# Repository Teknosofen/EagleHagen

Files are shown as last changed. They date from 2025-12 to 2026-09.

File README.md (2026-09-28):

# Eaglehagen CO₂ Monitor

ESP32-S3 (LilyGO T-Display S3) replacement for a legacy PIC16F876A/LabVIEW setup. It reads a MedAir MaCO2-V3 side-stream CO₂ analyser plus O₂ and volume sensors, and shows the data on the built-in screen, on a phone or tablet over WiFi, and as a serial stream over USB.

All documentation is public in this repository: **https://github.com/Teknosofen/EagleHagen**

| Document | For |
|---|---|
| [USER_GUIDE.md](USER_GUIDE.md) | Operating the device: screen, buttons, web page, data export, PC connection, troubleshooting |
| [documentation/DESIGN_REFERENCE.md](documentation/DESIGN_REFERENCE.md) | Hardware, sensor protocol, firmware architecture, interfaces, build setup, history |
| [documentation/Eaglehagen_Basic_Setup.pptx](documentation/Eaglehagen_Basic_Setup.pptx) | Printable basic-setup handout (9 pages) |
| [documentation/Images/](documentation/Images/) | Photos of the unit, closed and opened |
| [documentation/Mech CAD/](documentation/Mech%20CAD/) | Enclosure model (Autodesk Fusion 360 archive, `.f3z`) |
| [tools/Eaglehagen_Serial_Monitor.html](tools/Eaglehagen_Serial_Monitor.html) | Stand-alone PC monitor over USB: accepts both output formats (LabVIEW and ASCII), records to CSV. Also downloadable from the device's web page (embedded in the firmware at build time). Open in Chrome/Edge; add `#demo` for synthetic data |

**Quick start:** power on → join WiFi `EAGLEHAGEN` (no password) → open `http://eaglehagen.local` (or `http://192.168.4.1`).

**Build:** `pio run -t upload` (PlatformIO). No library edits are needed; the display setup is in [include/TFT_eSPI_Setup.h](include/TFT_eSPI_Setup.h).

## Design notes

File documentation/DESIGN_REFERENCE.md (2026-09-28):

# Eaglehagen CO₂ Monitor — Design & Technical Reference

This is the single design reference for the Eaglehagen monitor: hardware, sensor protocol, firmware architecture, interfaces, build setup and history. It combines the earlier documents `TECHNICAL_OVERVIEW.md`, `SOFTWARE_ARCHITECTURE.md`, `ESP32_MedAir_Implementation.md`, `CO2_Analyzer_Serial_Interface.md`, `LIBRARY_DEPENDENCIES.md`, `LOGO_IMPLEMENTATION_FINAL.md`, `Setup.txt` and `README.md`. Those files remain available in git history (last present in commit `65a4f93`).

For operating instructions, see [../USER_GUIDE.md](../USER_GUIDE.md).

**Repository:** all documentation, the firmware source and the PC monitor page are in the public repository **https://github.com/Teknosofen/EagleHagen**. The latest version of this document is always there.

Where the older documents contradicted each other, **the current source code (`src/`, `include/`) was taken as the truth**. Superseded statements are listed in [§13](#13-superseded-design-decisions-and-corrections) so the history isn't lost.

---

## Contents

1. [Background and goals](#1-background-and-goals)
2. [Hardware](#2-hardware)
3. [MaCO2-V3 CO₂ sensor and protocol](#3-maco2-v3-co-sensor-and-protocol)
4. [Legacy PIC16F876A system](#4-legacy-pic16f876a-system)
5. [Firmware architecture](#5-firmware-architecture)
6. [USB host output (LabVIEW / ASCII)](#6-usb-host-output-labview--ascii), including the PC monitor page (§6.4)
7. [WiFi and web interface](#7-wifi-and-web-interface)
8. [LCD user interface](#8-lcd-user-interface)
9. [Configuration constants](#9-configuration-constants)
10. [Build environment and libraries](#10-build-environment-and-libraries)
11. [Testing and developer troubleshooting](#11-testing-and-developer-troubleshooting)
12. [Future enhancements](#12-future-enhancements)
13. [Superseded design decisions and corrections](#13-superseded-design-decisions-and-corrections)

---

## 1. Background and goals

The project replaces a roughly 20-year-old monitoring setup built for Dr. Eaglehagen (Örnhagen). In that setup a **PIC16F876A** combined data from a **MedAir MaCO2-V3** CO₂ analyser with two analog readings (O₂ and volume) and sent them to a PC running **LabVIEW**.

Goals of the ESP32 replacement:
- One device replaces the PIC board and the need for a PC during normal monitoring.
- Local display (TFT) and remote display (WiFi web page on phone or tablet).
- USB virtual COM port with a PIC-style data stream, so the existing LabVIEW program can keep working.
- Full bidirectional control of the analyser (start pump, zero calibration) from the web, USB or a hardware button.

### Old vs new signal flow

**Legacy (split serial):**
```
                    ┌─────────────────────┐
          ┌────────>│  MedAir MaCO2-V3    │
          │  TX     │   CO2 Analyzer      │
    Host/LabVIEW    └──────────┬──────────┘
          │                    │ TX (data out) 9600 8N1
          │         ┌──────────▼──────────┐
          │  RX     │  PIC16F876A         │◄─── AN0 (O2 sensor)
          └─────────┤  RX: from MaCO2     │◄─── AN1 (Volume sensor)
                    │  TX: to host        │
                    └─────────────────────┘
1. Host TX ──► MaCO2 RX       (commands; bypasses PIC completely)
2. MaCO2 TX ──► PIC RX        (8-byte packets)
3. PIC samples AN0/AN1, combines, PIC TX ──► Host RX
```
The PIC never saw the commands. It only received and enriched data.

**New (ESP32):**
```
MaCO2-V3 ◄──UART1 (bidirectional, 9600)──► ESP32-S3 (T-Display S3)
O2 sensor ──► GPIO1 ADC                      │  ├─ TFT 170×320
Vol sensor ─► GPIO2 ADC                      │  ├─ USB-C CDC ◄──► PC / LabVIEW (data + commands)
                                             │  └─ WiFi AP   ◄──► browsers (data + commands)
```
- The ESP32 owns the full UART link, so commands are visible and logged.
- The onboard 12-bit ADC replaces the PIC's AN0/AN1.
- USB-C provides power, programming, debug output and the LabVIEW data stream.

### Operating modes

| Mode | Topology | Use |
|---|---|---|
| USB only | MaCO2 ↔ ESP32 ↔ USB-C ↔ PC/LabVIEW | Drop-in replacement for PIC |
| WiFi only | MaCO2 ↔ ESP32 ↔ WiFi ↔ browser | Standalone bedside monitoring, no PC |
| Dual | Both at once | LabVIEW logging plus quick checks on a phone |
| USB + PC monitor page | MaCO2 ↔ ESP32 ↔ USB-C ↔ Chrome/Edge page (§6.4) | Live display and unlimited CSV recording on a PC, no LabVIEW |

### Migration plan (from original design)

1. **Parallel testing:** keep the PIC system, build the ESP32, verify LabVIEW data against the PIC output.
2. **Soft migration:** use the ESP32 normally and keep the PIC as backup.
3. **Full migration:** retire the PIC hardware.
4. **Web-first (optional):** move away from LabVIEW and export data from the web UI.

Hardware migration: remove the PIC board, add the T-Display S3, connect the O₂ and volume sensors to the ESP32 ADC (with dividers if they output 5 V), and replace the old RS-232 cable with one USB-C cable. The MaCO2 serial link (9600 baud) is unchanged.

```
Old:  MaCO2 TX → PIC RX;  PIC TX → RS232 → PC;  PC → MaCO2 RX;  O2 → AN0;  Vol → AN1
New:  MaCO2 TX → ESP32 UART1 RX (level shifted);  ESP32 UART1 TX → MaCO2 RX;
      O2 → GPIO1;  Vol → GPIO2;  ESP32 USB-C → PC (virtual COM)
```

---

## 2. Hardware

### 2.1 LilyGO T-Display S3

- ESP32-S3 dual-core, 240 MHz, WiFi/Bluetooth, 16 MB flash, OPI PSRAM
- 1.9" ST7789 TFT, 170×320, driven over an **8-bit parallel bus** (TFT_eSPI setup 206), used in portrait orientation
- Two push buttons: **GPIO0 (BOOT)** and **GPIO14**
- USB-C with native USB CDC (programming, debug, host data, 5 V power)
- Pin-layout picture: [Lilygo-T-display_pinlayout.webp](Lilygo-T-display_pinlayout.webp)

### 2.2 Pin assignment (current firmware)

| Pin | Function | Notes |
|-----|---|---|
| GPIO 17 | UART1 TX → MaCO2 RX | 9600 8N1, direct 3.3 V drive |
| GPIO 18 | UART1 RX ← MaCO2 TX | 9600 8N1, **via level shifter** |
| GPIO 1 | ADC — O₂ sensor | 12-bit, 11 dB attenuation |
| GPIO 2 | ADC — Volume sensor | 12-bit, internal weak pull-down enabled |
| GPIO 14 | Button — pump start, labelled **"Restart pump"** | INPUT_PULLUP, interrupt driven |
| GPIO 0 | Button — output-format toggle (BOOT), labelled **"Select output"** | INPUT_PULLUP, interrupt driven; strapping pin |
| GPIO 15 | TFT/peripheral power enable | OUTPUT, driven HIGH at start |
| GPIO 38 | TFT backlight | Handled by TFT_eSPI |
| GPIO 5–8 (+ data bus) | TFT parallel interface (RST=5, CS=6, DC=7, WR=8) | Pre-wired on the board |

### 2.3 Power supply

```
+12 V in ──┬──► MaCO2 sensor (+12 V)
           └──► 7805 ──► +5 V ──► ESP32 USB-C / 5 V
                [100 nF + 10 µF on input and output]
```
- **7805** (TO-220): input 7–35 V, output 5 V at up to 1 A. Add a heatsink if the load exceeds about 500 mA. If it runs too hot, use a buck converter (e.g. LM2596).
- **Power budget (estimated):** MaCO2 about 200–300 mA at 12 V. ESP32-S3 about 200–300 mA at 5 V (WiFi about 80 mA of that), backlight about 100 mA. Total at 5 V is about 300–400 mA.
- The board can also be powered from the PC over USB-C alone, for example on the bench.
- Option: 18650 Li-ion battery for portable use (not implemented).

### 2.4 Level shifting (MaCO2 5 V TTL ↔ ESP32 3.3 V)

**MaCO2 TX → ESP32 RX:** resistor and Zener clamp.
```
MaCO2 TX (5 V) ── 1 kΩ ──┬──► ESP32 GPIO18 (RX)
                         │
                   3.3 V Zener (1N5226B / BZX79-C3V3), cathode to signal
                         │
                        GND
```
This is simple and reliable at 9600 baud.

**ESP32 TX → MaCO2 RX:** direct connection. 3.3 V is above the 5 V TTL high threshold (about 2.0 V).

**Alternative:** a 74LVC245 powered from 3.3 V (5 V-tolerant inputs), with DIR = HIGH and OE = LOW.

### 2.5 Analog inputs

- ESP32-S3 SAR ADC, 12 bits (0–4095), 11 dB attenuation (usable range about 0–3.1 V). Accuracy is about ±2 % and up to about 83 kS/s.
- Voltage correction uses the ESP-IDF 5 **`adc_cali` curve-fitting** scheme (eFuse based), with a linear fallback. The legacy `esp_adc_cal` API **must not** be used: with Arduino core 3.x, linking it next to the driver behind `analogRead()` makes ESP-IDF abort at boot (`check_adc_oneshot_driver_conflict`).
- **O₂ sensor:** Servomex **PM1111E** paramagnetic cell (no reagent consumption, no drift). Linear 0–1 V output, connected directly.
- **Volume sensor:** analog pressure/flow transducer.
- If a sensor outputs 0–5 V, add a divider: R1 = 10 kΩ (series) and R2 = 20 kΩ (to GND) gives 3.33 V at 5 V. 10k/22k gives 3.44 V, which is marginal.
- Add 100 nF from each ADC pin to GND for noise filtering.

### 2.6 Bill of materials

| Component | Part | Qty | Notes |
|---|---|---|---|
| Microcontroller | LilyGO T-Display S3 | 1 | 1.9" display |
| Regulator | LM7805 TO-220 | 1 | +12 V → +5 V |
| Level-shift resistor | 1 kΩ ¼ W | 1 | UART RX |
| Zener | 1N5226B 3.3 V 500 mW | 1 | UART RX clamp |
| Divider R1 / R2 | 10 kΩ / 20 kΩ ¼ W | 2 + 2 | Only for 5 V sensors |
| Ceramic cap | 100 nF | 6 | Decoupling + ADC filter |
| Electrolytic cap | 10 µF 25 V | 2 | 7805 in/out |
| Power connector | 2-pin screw terminal | 1 | +12 V in |
| Heatsink | TO-220 | 1 | If needed |
| Protoboard/PCB | — | 1 | |

Estimated cost about USD 25–30, excluding sensors.

### 2.7 Enclosure, photos and mechanical CAD

The monitor is built into a black, 3D-printed enclosure with a hinged lid.

**Photos** ([Images/](Images/)):

| Photo | Shows |
|---|---|
| [IMG_1770.jpg](Images/IMG_1770.jpg) | The closed unit from the front: "Örnhagens monitor" label, display window with the LCD, the water trap mounted on the side, the USB-C cable, and the two labelled push buttons **"Restart pump"** (GPIO14) and **"Select output"** (GPIO0/BOOT). |
| [IMG_1771.jpg](Images/IMG_1771.jpg) | The unit opened: analyser electronics and pneumatic tubing in the base, and the LilyGO T-Display S3 with the interface electronics mounted in the lid, connected by a ribbon cable. |

**Mechanical CAD:** [Mech CAD/EagleHagen_Gas_analyzer.f3z](Mech%20CAD/EagleHagen_Gas_analyzer.f3z) is the enclosure model as an Autodesk Fusion 360 archive. Open it in Fusion 360 with *File → Open → Open from my computer…*. The `.f3z` format keeps the design and its referenced components together in one file.

---

## 3. MaCO2-V3 CO₂ sensor and protocol

### 3.1 Device

- **Medair MaCO2-V3 OEM module**, made by MedAir AB (Delsbo, Sweden)
- Side-stream capnography: NDIR CO₂ measurement, internal sample pump (about 50 mL/min, typical for MedAir products), moisture trap
- MedAir was acquired by **Nonin Medical, Inc.** in 2006. The technology lives on in Nonin RespSense and LifeSense products and the CAP201 OEM module. Contact: oem@nonin.com (OEM sales), info@nonin.com (support), https://www.nonin.com
- No manufacturer datasheet for the MaCO2-V3 is available online. The protocol below was reverse-engineered from the PIC firmware and the LabVIEW program, then **corrected against captured sensor data** during ESP32 development.

### 3.2 Serial settings

9600 baud, 8 data bits, no parity, 1 stop bit, no flow control, asynchronous.

### 3.3 Initialization handshake

```
MaCO2 → host : 0x06            (start byte)
host  → MaCO2: 0x1B (ESC)      (acknowledge)
MaCO2 → host : 7 bytes         (init data, discarded)
```
The firmware waits up to 10 s (`MaCO2Parser::initialize`). On timeout it logs a warning and continues, and the parser picks up packets whenever they start arriving.

> In the PIC system the 0x1B went to the host port, not to the sensor. In the ESP32 firmware the ACK is written back to the MaCO2.

### 3.4 Data packet (8 bytes, about 8 Hz) — verified mapping

| Byte | Field | Range | Description |
|---|---|---|---|
| d[0] | status1 | 6 | Header / data-valid flag, always 0x06 for valid data |
| d[1] | status2 | 0–15 | Status bits (see 3.5) |
| d[2] | rr | 0–60 | Respiratory rate, breaths/min |
| d[3] | fico2 | 0–3 | FiCO₂, inspired baseline (mmHg) |
| d[4] | fco2_wave | 0–50 | Real-time CO₂ waveform (mmHg), updated at 8 Hz |
| d[5] | fetco2 | 0–120 | Sensor EtCO₂. **Unreliable, not used.** |
| d[6] | reserved | — | Ignored |
| d[7] | checksum | 0–255 | `sum(d[0..6]) & 0xFF` |

### 3.5 Status byte 2 (d[1])

| Bit | Meaning | Firmware interpretation |
|---|---|---|
| 0 | Pump | **0 = running (OK), 1 = stopped (alarm)** |
| 1 | Leak | 1 = leak detected |
| 2 | Occlusion | 1 = occlusion detected |
| 3–7 | Reserved | — |

Example: `0b00000110` means leak and occlusion. The LabVIEW diagram's own comment confirms this: "Status 2, bit 0 = pump stopped, bit 1 leak, bit 2 occlusion". An older reverse-engineered doc wrongly assumed bit 0 = 1 meant "running".

### 3.6 Commands (host → MaCO2)

| Byte | Command |
|---|---|
| `0xA5` | Start pump |
| `0x5A` | Zero calibration |
| (`F1` / `F2`) | Not command bytes. They are the LabVIEW **function keys**: F1 "Restart pump" sends `0xA5` and F2 "Zero CO2" sends `0x5A` (see §4.5). |

### 3.7 Firmware parsing details (`MaCO2Parser`)

- **Validation:** checksum must match, RR ≤ 60, and d[0] = 6 for `valid = true`. Sanity checks also reject EtCO₂ > 150.
- **Software EtCO₂:** the peak of d[4] is tracked during expiration. When the waveform falls below 25 % of the tracked peak (peak > 5, falling edge), the peak is latched as EtCO₂ and tracking restarts. The value stays 0 until the first detected breath.
- **Sync recovery:** after more than 3 consecutive errors, the parser collects bytes in a 16-byte sliding window. It looks for a 0x06 header with a valid checksum and plausible RR, waveform (≤ 50) and EtCO₂ (≤ 120). If no sync is found within 5 s, it flushes the UART buffer and restarts. Diagnostic lines prefixed with `#` go to the USB serial port.
- Statistics: `getPacketCount()`, `getErrorCount()`, `getLastPacketTime()`.

### 3.8 Clinical reference

- RR: breaths/min, adults typically 8–30.
- EtCO₂: normal 35–45 mmHg ≈ 4.5–6.0 kPa.
- FiCO₂: should be near 0. Raised values indicate rebreathing.
- Zero or absent CO₂ can mean no breathing, a disconnected cannula, occlusion or a malfunction.

---

## 4. Legacy PIC16F876A system

Kept here as a reference for LabVIEW compatibility and in case the old hardware needs service.

### 4.1 Hardware

- PIC16F876A at 20 MHz. UART TX = RC6, RX = RC7, 9600 8N1.
- **AN0 (RA0), O₂:** 10-bit ADC with Vref+ = AN3 and Vref− = Vss, left-justified, reported as 0–65535.
- **AN1 (RA1), Volume:** 10-bit ADC with Vdd/Vss reference, right-justified, 0–1023. LabVIEW labels it "Vol in ADC_Counts" / "DC_counts/liter".
- ADC acquisition about 20 µs plus conversion per channel. The PIC runs a continuous polling loop with no delays, so the frame rate follows the sensor.

### 4.2 PIC output frame

```
<ESC><CO2_ASCII><TAB><AN0_ADC><TAB><AN1_ADC><TAB><S1><S2><RR><B4><B5><CR><LF>
```
| # | Field | Encoding |
|---|---|---|
| 1 | ESC 0x1B | Start marker |
| 2 | CO₂ | 3 ASCII digits of d[4] (000–255) |
| 3,5,7 | TAB 0x09 | Separators |
| 4 | AN0 | 5 ASCII digits 00000–65535 |
| 6 | AN1 | 5 ASCII digits 00000–01023 |
| 8 | Status1 | Raw byte d[0] |
| 9 | Status2 | Raw byte d[1], 0 → 128 |
| 10 | RR | Raw byte d[2], 0 → 255 |
| 11 | d[4] | Raw byte, 0 → 255 (labelled "FetCO2" in the PIC analysis) |
| 12 | d[5] | Raw byte, 0 → 255 (labelled "FiCO2" in the PIC analysis) |
| 13–14 | CR LF | End of frame |

Example: `<ESC>045<TAB>32768<TAB>00512<TAB>[0x20][0x80][0x0F][0x2D][0x05]<CR><LF>`, meaning CO₂ 45, AN0 32768, AN1 512, S1 0x20, S2 0x80 (originally 0), RR 15, 45, 5.

How the LabVIEW program actually decodes this frame is described in §4.5.

### 4.3 Zero replacement and other quirks

- Zeros are replaced (Status2 → 128, RR/CO₂ bytes → 255) so no 0x00 byte reaches the host, where it could act as a string terminator. The PIC's `putchar()` refuses to send 0x00.
- As a result, 128 and 255 **can't be told apart from real zeros**.
- **Overrun recovery** runs once at start-up: read and discard two characters, clear CREN, set CREN.
- Limitations: no checksum on host frames, mixed ASCII and binary, fixed 9600 baud, no flow control.

### 4.4 Parsing pseudocode (PIC-style frame)

```python
def parse_frame(data):
    if data[0] != 0x1B:
        return None
    parts = data[1:].split(b'\t')
    co2, an0, an1 = int(parts[0]), int(parts[1]), int(parts[2])
    b = parts[3]
    status1 = b[0]
    status2 = 0 if b[1] == 128 else b[1]
    rr      = 0 if b[2] == 255 else b[2]
    x4      = 0 if b[3] == 255 else b[3]
    x5      = 0 if b[4] == 255 else b[4]
    return dict(co2=co2, an0=an0, an1=an1, status1=status1,
                status2=status2, rr=rr, byte4=x4, byte5=x5)
```
Synchronize on ESC (0x1B). Each frame ends with CR LF. A binary byte could itself be 0x09 or 0x0D, so a robust parser should use fixed positions after the third TAB.

### 4.5 The LabVIEW host program

Decoded from the block diagram of `Örnhagens O2-CO2-VOL-mätning_4.35_2_2026-0106.vi`.

**Frame, as stated in the diagram comment:** `<ESC>ABC<\t>DEFGH<\t>IJKLM<\t>OPQRS<\r><\n>`, **24 bytes**. The comment calls O "status 2" and P "status 1", but the wiring treats O as status 1.

**Reading:** `VISA Read` with a fixed byte count of **24** per loop iteration. The raw buffer is shown as hex and in `\`-codes format. The string is then cut at the TABs (Split String, String Subset offset 1 to skip each TAB).

| Field | LabVIEW processing | Expected content |
|---|---|---|
| ABC | Scan integer → "CO2 in mmHg" → ÷ **7.60** → "Convert to [%]" → × "CO2 Gain" → waveform chart | CO₂ in **mmHg** (7.6 mmHg ≈ 1 % at 760 mmHg) |
| DEFGH | Scan integer → "O2 in .1 %" → ÷ **10** → chart | O₂ in **0.1 %** units |
| IJKLM | Scan integer → "Vol in ADC_Counts" → ÷ "ADC_counts/liter" → chart | Volume, raw ADC counts |
| Binary tail | String → U8 array, then Index Array: | |
| index 1 | `= 6` → "Data Valid" (Status 1) | status1 |
| index 2 | Status 2 → bit 0 "Pump" (stopped), bit 1 "Leak", bit 2 "Occlusion" | status2 |
| index 3 | "RR" (U8) | RR |
| index 5 | "FiCO2" (U8) | see note |
| index 6 | "FetCO2" (U8) | see note |

**Note on indices 5 and 6** (inferred from the screenshot, not verified): the array most likely starts with the TAB before O, giving `[TAB, O, P, Q, R, S, CR, LF]`. Index 1 = O is then the 6-valued status1, which is consistent with the "Data Valid" check. Index 5 is then S and index 6 is CR (13). So the LabVIEW "FiCO2" indicator probably shows the last binary byte, and "FetCO2" shows a constant 13. Index 4 (R) is never read. Only the waveform, O₂, volume, RR and status are used for charts and alarms, so this doesn't affect the main display.

**Controls:**
- **F1 "Restart pump"** writes `A5` to the port. **F2 "Zero CO2"** writes `5A`. The diagram comment reads "Command A5:hex = start pump, 5A:hex Zero calibrate".
- **F5 / F6 / F7** adjust the sweep time (chart X-scale max). "Sample rate [1/s]" sets the X-scale multiplier.
- Data can be logged to file ("open or create" file refnum).

**Framing risks:**
- A fixed 24-byte read keeps frames aligned only if every frame is exactly 24 bytes and nothing else is sent on the port. One stray text line can shift all following reads. This is why the firmware mutes diagnostic text in Legacy mode (§5.8).
- If the VISA port is configured with a termination character (VISA default: enabled, `\n` = 0x0A), a read also stops early at any 0x0A byte. A binary byte equal to 10 (e.g. RR = 10, or status2 = 0x0A) then splits a frame. The PIC had the same weakness. The zero replacement only removes 0x00.

**Compatibility with the ESP32 firmware:**

| Field | LabVIEW expects | Firmware sends | Match |
|---|---|---|---|
| ABC | mmHg | mmHg | Yes |
| DEFGH | O₂ × 10 | O₂ × 10 | Yes |
| IJKLM | ADC counts 0–1023 | ADC counts 0–1023 | Yes |
| status1 / status2 / RR | raw | raw (with zero replacement) | Yes |
| bytes R, S | FiCO₂, FetCO₂ (see note) | FiCO₂ mmHg, EtCO₂ mmHg | Same units as the PIC |

The existing LabVIEW program works unchanged with the Legacy format.

**Frame sync:** the LabVIEW program has a separate preceding sequence, not visible in the diagram above, that searches for the **ESC byte (0x1B)** before the 24-byte reads. The firmware starts every frame with ESC, just as the PIC did (confirmed by the program's owner, 2026-09-27).

---

## 5. Firmware architecture

### 5.1 Modules

```
main.cpp  (orchestrator — setup, loop, timing, command routing)
  ├── MaCO2Parser     UART1 packet parsing, validation, sync recovery, EtCO2 tracking, commands
  ├── ADCManager      O2 + volume ADC read, moving-average filter, calibration → CO2Data
  ├── DisplayManager  TFT layout, waveform, metric boxes, status badges, splash screens
  ├── WiFiManager     Soft-AP, AsyncWebServer, WebSocket, JSON broadcast, embedded web page, command queue
  ├── DataLogger      USB CDC host output (Legacy LabVIEW / tab-separated ASCII)
  ├── DebugOut        Gated diagnostic text on the shared USB port (DebugLog.h)
  └── Button ×2       Interrupt-driven, debounced (50 ms), short/long press (1000 ms)
```
```
  UART1 (MaCO2)   GPIO ADC   TFT (parallel)   WiFi/Web   USB CDC
       ▲             ▲             ▲              ▲          ▲
  MaCO2Parser    ADCManager   DisplayManager  WiFiManager  DataLogger
       └─────────────┴──────── main.cpp ─────────┴──────────┘
```

**Files:** `src/*.cpp`, headers in `include/` (`MaCO2Parser.h`, `ADCManager.h`, `DisplayManager.h`, `WiFiManager.h`, `DataLogger.h`, `DebugLog.h`, `Button.hpp`, `ChartJS.h`, `TFT_eSPI_Setup.h`, and the generated `MonitorPage.h`). `tools/` holds the PC monitor page and `scripts/` its build-time embedding script (§6.4). Early prototype code (an ESP8266 sketch in `EagleHagen/` and an old parser in `_older_stuff/`) was never part of the build and has been removed. It remains in git history, e.g. `git show 2cba5e9:EagleHagen/GasAnalyzer.cpp`.

### 5.2 Key interfaces

```cpp
// MaCO2Parser
bool initialize(HardwareSerial& serial, unsigned long timeout_ms = 10000);
bool parsePacket(HardwareSerial& serial, CO2Data& data);   // non-blocking
void sendCommand(HardwareSerial& serial, MaCO2Command cmd); // CMD_START_PUMP=0xA5, CMD_ZERO_CAL=0x5A
bool isPumpRunning(const CO2Data&) const;   // (status2 & 0x01) == 0
bool isLeakDetected(const CO2Data&) const;
bool isOcclusionDetected(const CO2Data&) const;
bool isDataValid(const CO2Data&) const;

// ADCManager
bool begin();
void update(CO2Data& data);
void setO2Calibration(float v_at_0_percent, float v_at_100_percent);
void setVolumeCalibration(float ml_per_volt, float offset_ml);
void setFilterSize(uint8_t size);          // class default 10, main.cpp sets 5

// DisplayManager
bool begin();
void showSplash(const char* title, const char* subtitle = nullptr);
void clearScreen();
void updateAll(const CO2Data& data);
void addWaveformPoint(uint16_t co2_value);
void setNetworkInfo(const char* ssid, const char* ip);
void setOutputFormatName(const char* name);
void setBacklight(uint8_t brightness);

// WiFiManager
bool beginAP(const char* ssid, const char* password);      // empty password → open AP
bool beginStation(const char* ssid, const char* password, timeout);
bool startServer();
bool beginHostname(const char* hostname);  // mDNS + AP DNS answer for <hostname>.local
void update(const CO2Data& data);    // WebSocket broadcast
void loop();
bool hasCommand();  uint8_t getCommand();
void setDataLogger(DataLogger*);     // lets the web page change output format

// DataLogger
void sendData(Stream&, const CO2Data&);   // dispatches on current format
void setOutputFormat(OutputFormat);        // FORMAT_LEGACY_LABVIEW=0, FORMAT_TAB_SEPARATED=1; also gates DebugOut
void setOutputEnabled(bool);

// DebugOut (global DebugLogger, a Print subclass)
DebugOut.printf(...); DebugOut.println(...);  // use instead of Serial.print* for all diagnostics
void setEnabled(bool);                        // called by DataLogger
```

### 5.3 Shared data structure `CO2Data`

| Field | Type | Filled by | Unit |
|---|---|---|---|
| co2_waveform | uint16_t | MaCO2Parser (d[4]) | mmHg |
| fetco2 | uint8_t | MaCO2Parser (software peak) | mmHg |
| fco2 | uint8_t | MaCO2Parser (d[3], FiCO₂) | mmHg |
| respiratory_rate | uint8_t | MaCO2Parser | bpm |
| status1, status2 | uint8_t | MaCO2Parser | flags |
| o2_adc | uint16_t | ADCManager | PIC-scaled 0–65535 |
| vol_adc | uint16_t | ADCManager | PIC-scaled 0–1023 |
| o2_percent | float | ADCManager | % |
| volume_ml | float | ADCManager | mL |
| timestamp | uint32_t | millis() | ms |
| valid | bool | MaCO2Parser | — |

> **Unit convention:** CO₂ values travel through the firmware as **raw mmHg**. Conversion to kPa (× 0.133322) happens only at the output boundary: LCD, browser JavaScript, serial output and exports.

### 5.4 Data flow

```
MaCO2 ──UART──► MaCO2Parser ──► co2_waveform, fetco2 (sw peak), fco2, rr, status
O2    ──ADC───► ADCManager  ──► o2_percent, o2_adc
Vol   ──ADC───►             ──► volume_ml, vol_adc

CO2Data ──► DisplayManager → waveform (mmHg scale), numbers (kPa)
        ──► WiFiManager    → WebSocket JSON (mmHg) → browser converts to kPa (display, charts, CSV/JSON)
        ──► DataLogger     → Legacy: CO2 in mmHg, O2 as %×10  │ ASCII: CO2 kPa, O2 %
```

ADC readings are taken only when a new sensor packet arrives, so the ADC rate follows the sensor rate (about 8 Hz).

### 5.5 Timing (main loop, non-blocking)

| Task | Interval | Rate |
|---|---|---|
| Data acquisition (parse + ADC) | 100 ms | 10 Hz, polled faster than the sensor's 8 Hz to avoid buffer build-up |
| LCD refresh | 50 ms | 20 Hz |
| WebSocket broadcast | 125 ms | 8 Hz |
| USB host output | 100 ms | 10 Hz, only when `valid` |

`main.cpp` defines `LABVIEW_UPDATE_INTERVAL_MS = 200`, but the host-output block actually uses `DATA_UPDATE_INTERVAL_MS` (100 ms). The measured rate is about 9–10 frames/s, limited by the sensor's ~8–10 Hz packet rate. The web JSON export's `sample_rate_hz: 8` refers to the WebSocket rate.

### 5.6 Command routing

| Source | Path |
|---|---|
| IO14 button (short press) | `CMD_START_PUMP` → MaCO2 |
| BOOT button | Toggle `DataLogger` format; LCD `Out:` label updated |
| Web (WebSocket `{"cmd":"start_pump"|"zero_cal"}` or `POST /command`) | Queued in WiFiManager → MaCO2 |
| USB CDC byte `0xA5` / `0x5A` | Forwarded to MaCO2; other bytes ignored |
| Web `GET /api/setFormat?format=0|1` | Sets DataLogger format |

### 5.7 Start-up sequence

1. USB CDC at 115200. Banner is printed.
2. Display init. Splash "Teknosofen / Initializing…".
3. ADC init: volume-pin pull-down, filter 5, calibration.
4. Splash "Connecting sensor…". UART1 at 9600. MaCO2 handshake (≤ 10 s).
5. WiFi AP, web server, mDNS and DNS responder for `eaglehagen.local`.
6. DataLogger (default **Legacy LabVIEW**), linked to WiFiManager.
7. Buttons.
8. Splash "Ready! / IP: …". Main screen.

Because the default format is Legacy, the start-up log is muted (§5.8). Build with `-DDEBUG_LOG_ALWAYS=1` to see it.

### 5.8 Diagnostic output (`DebugLog.h`)

Diagnostics and host data share the single USB CDC port. All firmware diagnostics go through `DebugOut` (never `Serial.print*` directly):

| Host output mode | Diagnostics |
|---|---|
| Legacy LabVIEW (output enabled) | **Muted.** The port carries only 24-byte frames (§4.5). |
| Tab-separated ASCII | Sent, with every line prefixed `# ` (lines already starting with `#` are left alone) |
| Host output disabled | Sent, prefixed |

`DataLogger::setOutputFormat()` / `setOutputEnabled()` update the gate automatically. `-DDEBUG_LOG_ALWAYS=1` in `build_flags` forces diagnostics on for development. Note that this breaks LabVIEW framing.

Remaining caveat: web-server callbacks run in the AsyncTCP task. In ASCII mode, a diagnostic line from that task can in rare cases interleave with a data line.

---

## 6. USB host output (LabVIEW / ASCII)

USB-C enumerates as a CDC virtual COM port (`ARDUINO_USB_CDC_ON_BOOT=1`, ESP32-S3 USB-Serial/JTAG, VID:PID `303A:1001`): "USB Serial Device (COMx)" on Windows ("Seriell USB-enhet" in Swedish), `/dev/ttyACM0` on Linux. Chrome's port picker may list it as "USB JTAG/serial debug unit". The baud rate doesn't matter for USB CDC, and 115200 8N1 is the convention. The same port carries programming, debug messages and data.

> Diagnostic text is muted in Legacy mode and `#`-prefixed in ASCII mode (§5.8). Parsers of the ASCII format should skip lines starting with `#`.

### 6.1 Legacy LabVIEW format (default)

```
<ESC> AAA <TAB> BBBBB <TAB> CCCCC <TAB> s1 s2 RR fi et <CR><LF>
```
| Field | Format | Value |
|---|---|---|
| AAA | `%03d` | CO₂ waveform, **mmHg** (as the PIC; LabVIEW ÷ 7.60 → %) |
| BBBBB | `%05d` | O₂, **% × 10** (209 = 20.9 %) |
| CCCCC | `%05d` | Volume ADC, PIC 10-bit scaled 0–1023 |
| s1 | byte | status1 |
| s2 | byte | status2 (0 → 128) |
| RR | byte | respiratory rate (0 → 255) |
| fi | byte | FiCO₂, mmHg (0 → 255) |
| et | byte | EtCO₂ (software peak), mmHg (0 → 255) |

> **Compatibility:** all fields use the units the existing LabVIEW program expects (§4.5), so it works without changes. The frame is always exactly 24 bytes.

### 6.2 Tab-separated ASCII

```
CO2_kPa<TAB>O2%<TAB>RR<TAB>Volume_mL<TAB>Status1<TAB>Status2<CR><LF>
e.g.  4.3	20.9	14	320	6	0
```
CO₂ has 1 decimal (kPa), O₂ has 1 decimal (%), RR, volume (integer mL) and status bytes are decimal.

### 6.3 Selecting the format

BOOT button, web radio buttons, or `GET /api/setFormat?format=0` (legacy) / `1` (tab-separated). The setting isn't stored and resets to Legacy at power-up.

### 6.4 PC monitor page (`tools/Eaglehagen_Serial_Monitor.html`)

A stand-alone, single-file web page that displays and records the USB stream on a PC without LabVIEW. It has no dependencies: charts are drawn on `<canvas>`, the logo is embedded as base64, and nothing is loaded from the internet. User instructions are in section 7 of the user guide.

**It accepts both host output formats.** The parser handles the Legacy LabVIEW format (§6.1) and the tab-separated ASCII format (§6.2) in the same stream, so a BOOT-button switch while connected is followed without reconnecting. The *Data format* selector can force one format, but *Auto-detect* is the default.

**Distribution: the device carries its own copy.** The page is embedded in the firmware and offered as a download from the built-in web page (`GET /monitor.html`, §7.2), so no external files are needed. The intended workflow:
1. Over WiFi, open the device's web page and click **Download** under *PC monitor page (USB)*.
2. Open the saved file in Chrome or Edge, and connect with the USB cable.

The page can't run directly from `http://192.168.4.1`. Web Serial requires a secure context (`https://`, `localhost` or `file://`), and plain HTTP to the device is not one. That's why it's a download, not a route to browse. All three presentation paths remain: the LCD, the WiFi web page, and this page over USB.

**Build integration:**
- `scripts/embed_monitor_page.py`, a PlatformIO `pre:` extra script, gzips `tools/Eaglehagen_Serial_Monitor.html` at every build (level 9, `mtime=0`, so identical input gives identical output) into `include/MonitorPage.h` (`MONITOR_PAGE_GZ`, `MONITOR_PAGE_GZ_LEN`).
- The header is rewritten only when the page changes, so unchanged builds don't recompile. It's generated, so it's in `.gitignore`.
- The HTML file in `tools/` is the only source to edit. Every firmware build serves the matching version.
- Cost: about 56 KB of HTML (including the base64 logo) becomes about 28 KB of flash.

**Serial access:** Web Serial API, so only **Chrome and Edge** (desktop). It works from a `file://` URL. The browser's own port picker must be used once per device ("Add port…"). After that, `navigator.serial.getPorts()` lists the device in the page's own selector, and Espressif devices (USB VID `0x303A`) are pre-selected. Plug and unplug events are handled. Only one program can hold the COM port, so LabVIEW must be closed first.

**Parser** (`StreamParser`, between the `PARSER START` / `PARSER END` markers):
- **ESC (0x1B)** starts a candidate LabVIEW frame. It's accepted only if all 24 bytes validate: TABs at offsets 4, 10 and 16, CR LF at 22–23, and numeric ASCII fields. Otherwise the parser skips one byte and resyncs. Validating the whole frame keeps binary tail bytes equal to 0x1B or 0x0A (e.g. EtCO₂ = 27 mmHg, RR = 10) from breaking the framing.
- **Other bytes** are read as a text line up to LF. A line of six numeric TAB-separated fields is an ASCII frame. A line starting with `#` is a device message and goes to the log. Other printable text also goes to the log, and binary junk is counted as an error.
- Zero replacement is undone (Status2 128 → 0; RR, FiCO₂ and EtCO₂ 255 → 0). LabVIEW CO₂ values (mmHg) are converted to kPa.
- In ASCII format, EtCO₂ isn't transmitted. The page computes it with the firmware's peak-tracking algorithm (`EtTracker`, §3.7). FiCO₂ is unavailable.
- Volume is **ADC counts** in LabVIEW format and **mL** in ASCII format. The page labels the unit accordingly and stores them in separate CSV columns.
- **Tests:** `node tools/tests/test_monitor_parser.js` extracts the parser from the HTML and runs 10 checks. They cover a real device capture (`tools/tests/capture_labview.bin`) fed in odd-sized chunks, a mid-frame start, binary bytes that look like frame markers, ASCII with `#` lines, a format switch mid-stream, random garbage, and the EtCO₂ tracker. Run them after editing the parser.

**Recording:** every frame received while connected is kept, with no time limit (unlike the 2-minute web buffer). **CSV** columns: `Timestamp, Elapsed(s), CO2_Waveform(kPa), FetCO2(kPa), FiCO2(kPa), RR(bpm), O2(%), Volume(mL), Volume(ADC), Pump_Running, Leak_Detected, Occlusion_Detected, Status1, Status2, Format`. The *Swedish Excel* style uses `;`, decimal commas and a UTF-8 BOM. Files are saved through `showSaveFilePicker` where available, otherwise downloaded.

**Other features:**
- Start pump (`0xA5`) and zero calibration (`0x5A`, with confirmation) are written to the port.
- Dark and light themes. The theme, baud rate and CSV style are remembered in `localStorage`.
- Stale-data indication after 2 s without frames.
- `#demo` in the URL generates synthetic LabVIEW frames through the same parser.

---

## 7. WiFi and web interface

### 7.1 Network

- **Soft-AP** `EAGLEHAGEN`, **open** (no password), IP `192.168.4.1`.
- **Hostname `eaglehagen.local`** (`HOSTNAME` in `main.cpp`):
  - **mDNS** (`ESPmDNS`, `_http._tcp` service on port 80) for Windows, macOS, iOS and Linux.
  - A **DNS responder** (`DNSServer`, port 53) answers only `eaglehagen.local` with the AP IP. The AP's DHCP hands out the ESP32 as DNS server, and many Android devices resolve `.local` through unicast DNS instead of mDNS. All other names get NXDOMAIN, so phones don't show a captive-portal "sign in" pop-up.
  - `192.168.4.1` always works as a fallback.
- Station mode exists in `WiFiManager::beginStation` but isn't enabled (`WIFI_AP_MODE = true`).
- ESPAsyncWebServer on port 80. Multiple simultaneous clients are supported. About 8 KB/s per client at 8 Hz.

### 7.2 Endpoints

| Method / path | Purpose |
|---|---|
| `GET /` | Dashboard HTML, embedded in `WiFiManager.cpp` (`getIndexHTML()`) |
| `GET /chart.min.js` | Chart.js, **gzip-compressed and embedded** (`include/ChartJS.h`), so no internet is needed |
| `GET /monitor.html` | The PC monitor page (§6.4), gzip-embedded (`include/MonitorPage.h`, generated at build). Sent with `Content-Disposition: attachment` so the browser saves it as `Eaglehagen_Serial_Monitor.html`. |
| `WS /ws` | Pushes JSON at 8 Hz; accepts `{"cmd":"start_pump"}` / `{"cmd":"zero_cal"}` |
| `GET /data` | Current values as JSON |
| `POST /command` | Form field `cmd=start_pump|zero_cal` |
| `GET /api/setFormat?format=0|1` | Select host-output format |

### 7.3 WebSocket JSON (per frame)

```json
{ "timestamp": 123456, "co2_waveform": 32, "fetco2": 40, "fco2": 0, "rr": 14,
  "o2_percent": 20.9, "volume_ml": 320.0, "status1": 6, "status2": 0, "valid": true,
  "pump_running": true, "leak_detected": false, "occlusion_detected": false,
  "output_format": 0 }
```
`output_format` is the current host format (0 = Legacy, 1 = tab-separated). The page uses it to keep the format radio buttons in sync, including changes made with the BOOT button.
CO₂ fields are in **mmHg**. The browser converts them to kPa.

### 7.4 Page layout

```
┌─────────────────────────────────────────────────────────┐
│ [logo] Örnhagens Monitor                by Teknosofen   │
│                    [Connected] [Pump] [Leak] [Occl]     │
├─────────────────────────────────────────────────────────┤
│ End-Tidal CO₂ [kPa] │ CO₂ [kPa] │ RR [bpm] │ O₂ [%] │ Volume [mL] │
├─────────────────────────────────────────────────────────┤
│ CO₂ waveform chart (kPa)                                │
│ O₂ chart (%)                                            │
│ Volume chart (mL)                                       │
├─────────────────────────────────────────────────────────┤
│ [Start Pump] [Zero Calibration] [Save CSV] [Save JSON] [Clear Data] │
│ USB Host Output Format (10 Hz): (•) Legacy (LabVIEW) ( ) Tab-Separated ASCII │
│ Data Points: n / 960 (2 min buffer) | Duration m:ss                 │
│ PC monitor page (USB) – save it, open in Chrome/Edge     [Download] │
└─────────────────────────────────────────────────────────┘
```
- Status badges: Connected/Reconnecting reflects the WebSocket state, with auto-reconnect every 3 s. Pump/Leak/Occl turn red with a pulse animation on alarm (`Pump!`, `Leak!`, `Occl!`).
- Charts: Chart.js, updated with `update('none')` (no animation) for performance.
- Responsive layout for phone, tablet and desktop.
- The format radio buttons have no default in the HTML. They're set from `output_format` in each WebSocket frame.

### 7.5 Data buffer and export (client-side)

- `dataLog[]` in the browser keeps the last **960 samples** (2 min at 8 Hz). Older samples are shifted out.
- **CSV:** `medair_co2_data_<ISO-timestamp>.csv`, columns `Timestamp, Elapsed(s), CO2_Waveform(kPa), FetCO2(kPa), FiCO2(kPa), RR(bpm), O2(%), Volume(mL), Pump_Running, Leak_Detected, Occlusion_Detected, Status1, Status2`.
- **JSON:** `{ metadata: { export_time, recording_start, duration_seconds, data_points, sample_rate_hz: 8, device, firmware, units: {…} }, data: [...] }`.
- **Clear Data** empties `dataLog` and the chart buffers.

### 7.6 Logo and branding

- The web logo is the Örnhagen "E" WebP (234×250 px, about 10 KB, about 13.4 KB as base64). It's embedded in an `<img>` data-URI, 40 px high, left of the title.
- Why embed everything (HTML, CSS, JS, logo, Chart.js) in flash: no SPIFFS/LittleFS, a single firmware upload, simpler deployment, and the page works without internet.
- Colour palette shared with the TFT: soft grey background (#85BA / `TFT_LOGOBACKGROUND`), soft blue primary (#5497 / `TFT_LOGOBLUE`), steel-blue and soft-green accents.

---

## 8. LCD user interface

### 8.1 Layout (170 × 320 portrait)

```
┌──────────────────────────┐  y=0
│  Ornhagen          ●WiFi │  Header (30 px), FreeSansBold, green dot when WiFi up
├──────────────────────────┤  y=30
│  CO2 waveform (grid)     │  120 px scrolling line, auto min/max scaling
│  CO2 Waveform            │
├──────────────────────────┤  y=150
│  FCO2   4.3   kPa        │  Metric box (50 px), real-time CO2
│  O2    20.9   %          │  Metric box (50 px), filtered O2
├──────────────────────────┤  y=250
│ [PUMP] [LEAK] [OCCL]     │  Status badges (green OK / red alarm)
│ ───────────────          │
│ SSID: EAGLEHAGEN         │
│ IP: 192.168.4.1          │
│ Out: LabVIEW             │  Host output format
└──────────────────────────┘  y=320
```
- Metric boxes redraw only when the formatted value changes (anti-flicker).
- Badges redraw only when `status2` or the format label changes.
- The waveform area is cleared and redrawn every 50 ms.
- EtCO₂, RR and volume aren't shown on the LCD (space). They're on the web page.

### 8.2 Splash screens and logo decision

`showSplash(title, subtitle)` draws the title in FreeSansBold12pt7b (`TFT_LOGOBLUE` on `TFT_LOGOBACKGROUND`, centred) and the subtitle in the small font (`TFT_SLATEBLUE`). The title is currently **"Teknosofen"** during start-up, then "Ready!".

A bitmap logo on the TFT was tried and dropped. Monochrome bitmap conversion kept producing rendering artefacts, and text is cleaner on a small screen, simpler, and saves about 480 bytes of PROGMEM. If a bitmap is wanted later, the options are TFT_eSPI `pushImage()` with pre-converted arrays, another converter (LCD Image Converter, online TFT tools), or loading from a filesystem.

---

## 9. Configuration constants

All in `src/main.cpp`:

```cpp
const char* WIFI_SSID     = "EAGLEHAGEN";
const char* WIFI_PASSWORD = "";          // open AP (was "co2monitor")
const bool  WIFI_AP_MODE  = true;
const char* HOSTNAME      = "eaglehagen";   // http://eaglehagen.local

#define UART_RX_MACO2  18
#define UART_TX_MACO2  17
#define O2_SENSOR_PIN   1
#define VOL_SENSOR_PIN  2
#define BUTTON_PIN     14   // pump start
#define BOOT0_PIN       0   // format toggle

#define DATA_UPDATE_INTERVAL_MS     100
#define DISPLAY_UPDATE_INTERVAL_MS   50
#define WIFI_UPDATE_INTERVAL_MS     125
#define LABVIEW_UPDATE_INTERVAL_MS  200   // defined but unused, see §5.5

adcManager.setFilterSize(5);
adcManager.setO2Calibration(0.0, 1.0);        // V at 0 % and at 100 % O2 (PM1111E 0–1 V)
adcManager.setVolumeCalibration(200.0, 0.0);  // mL per volt, offset mL — placeholder, calibrate!
```
Buttons: `Button(pin, longPressMs = 1000, debounceMs = 50)`.

Calibration is currently compile-time only. A web calibration page or Preferences/NVS storage (WiFi credentials, alarm limits, brightness, sweep speed, units) is a future item.

---

## 10. Build environment and libraries

### 10.1 PlatformIO (used by this project)

```ini
[env:lilygo-t-display-s3]
; pioarduino 53.03.10 = Arduino core 3.1.0 / ESP-IDF 5.3 (pinned, tested on hardware)
platform = https://github.com/pioarduino/platform-espressif32/releases/download/53.03.10/platform-espressif32.zip
board = lilygo-t-display-s3
framework = arduino
extra_scripts = pre:scripts/embed_monitor_page.py   ; embeds the PC monitor page (§6.4)
build_flags =
    -DUSER_SETUP_LOADED=1
    -include $PROJECT_INCLUDE_DIR/TFT_eSPI_Setup.h
    -DLILYGO_T_DISPLAY_S3=1
    -DARDUINO_USB_CDC_ON_BOOT=1
    -DCORE_DEBUG_LEVEL=0          ; no Arduino-core log lines on the LabVIEW port
    ; optional for development: -DDEBUG_LOG_ALWAYS=1
lib_deps =
    bodmer/TFT_eSPI@2.5.43
    bblanchon/ArduinoJson@7.4.2
    https://github.com/me-no-dev/ESPAsyncWebServer.git#ad3741d159f9cfd50c567e81b67f3bef1dc6d89f   ; 3.6.0
    https://github.com/me-no-dev/AsyncTCP.git#ef448a8a1dffe4ec1b72326dd5a26211ff227b49           ; 3.3.2
monitor_speed = 115200
monitor_filters = esp32_exception_decoder
```
**Everything is pinned** to the versions verified on the hardware (2026-09-27). Before this, the unpinned `platform = espressif32` silently moved to Arduino core 3.x, and the legacy ADC code then crash-looped at boot (§2.5). Upgrade deliberately: change one pin, `pio run -t clean`, flash, and check the USB frames and the display.

Commands: `pio run` (build), `pio run -t upload`, `pio device monitor`. No filesystem image is needed. Don't run `uploadfs`, because the web assets are compiled in.

### 10.2 TFT_eSPI configuration

The display setup is part of the project: [`include/TFT_eSPI_Setup.h`](../include/TFT_eSPI_Setup.h), a copy of TFT_eSPI's `Setup206_LilyGo_T_Display_S3.h` (ST7789, 170×320, 8-bit parallel, backlight GPIO38). `-DUSER_SETUP_LOADED=1` makes TFT_eSPI skip its own `User_Setup_Select.h`, and `-include` injects the project file into every compilation unit, including the library. The library files under `.pio/` are **not** edited, and a clean checkout builds as is.

PlatformIO does not track force-included headers. After changing `TFT_eSPI_Setup.h`, run `pio run -t clean` before building.

(Previously the library's `User_Setup_Select.h` line 133 had to be edited by hand to select Setup206. That edit was lost whenever `.pio/` was deleted.)

### 10.3 Libraries

| Library | Source | Purpose / used by | Licence |
|---|---|---|---|
| TFT_eSPI (Bodmer) 2.5.43 | PlatformIO registry | Display, DisplayManager | FreeBSD |
| ArduinoJson (B. Blanchon) 7.4.2 | PlatformIO registry | JSON for WebSocket/API, WiFiManager | MIT |
| ESPAsyncWebServer 3.6.0 (commit `ad3741d`) | GitHub URL (me-no-dev, now maintained as ESP32Async) | Async HTTP + WebSocket, WiFiManager | LGPL-3.0 |
| AsyncTCP 3.3.2 (commit `ef448a8`) | GitHub URL | Dependency of ESPAsyncWebServer | LGPL-3.0 |
| WiFi.h, ESPmDNS.h, DNSServer.h, esp_adc/adc_cali.h, HardwareSerial, Arduino.h | ESP32 Arduino core 3.1.0 | Built in | Apache-2.0 |

Measured footprint (2026-09-27 build): **1.23 MB flash** (18.7 % of the 6.5 MB application partition) and **49 KB static RAM** (15 %). Embedded assets: Chart.js about 69 KB gzip, the PC monitor page about 28 KB gzip. The board has 16 MB flash and 512 KB SRAM, so there's plenty of room.

Library links: TFT_eSPI https://github.com/Bodmer/TFT_eSPI · ESPAsyncWebServer https://github.com/me-no-dev/ESPAsyncWebServer · AsyncTCP https://github.com/me-no-dev/AsyncTCP · ArduinoJson https://arduinojson.org · ESP32 core https://github.com/espressif/arduino-esp32 · T-Display S3 https://github.com/Xinyuan-LilyGO/T-Display-S3 · Forum https://www.esp32.com

### 10.4 Arduino IDE (alternative)

PlatformIO is the supported build. The Arduino IDE can work, with these differences:

1. Boards Manager URL `https://raw.githubusercontent.com/espressif/arduino-esp32/gh-pages/package_esp32_index.json`, then install "esp32 by Espressif Systems" **3.1.0** (core 3.x is required: the ADC code uses `adc_cali`, and the DNS responder uses the async `DNSServer`).
2. Board settings: "LilyGO T-Display S3" or "ESP32S3 Dev Module". USB CDC On Boot: Enabled. CPU 240 MHz. Flash QIO 80 MHz, 16 MB. PSRAM: OPI. USB Mode: Hardware CDC and JTAG. Upload 921600.
3. Install TFT_eSPI and ArduinoJson from the Library Manager. Add ESPAsyncWebServer and AsyncTCP as .ZIP libraries from GitHub.
4. The IDE can't pass `-include`, so select the display setup in the library itself: in `TFT_eSPI/User_Setup_Select.h`, enable `#include <User_Setups/Setup206_LilyGo_T_Display_S3.h>` and comment out the default.
5. The IDE doesn't run `scripts/embed_monitor_page.py`, so `include/MonitorPage.h` must exist before compiling. Build once with PlatformIO to generate it, or remove the `/monitor.html` route.

### 10.5 Fallbacks if a library causes trouble

- **Minimal build:** remove WiFiManager. Display, sensor, ADC and USB output still work.
- Replace ESPAsyncWebServer with the built-in blocking `WebServer` (`WebServer server(80);`).
- Replace TFT_eSPI with LovyanGFX (faster) or Adafruit_ST7789 (simpler).

---

## 11. Testing and developer troubleshooting

### 11.1 Tests

- **Serial monitor** (`pio device monitor`, 115200): switch to ASCII format (BOOT button) to see `#`-prefixed diagnostics. To also see the start-up log, build with `-DDEBUG_LOG_ALWAYS=1`. `printStatus()` in `main.cpp` prints packet and error counts, WiFi clients, raw ADC and voltage, and flags. It isn't currently called, so hook it up temporarily when debugging.
- **Commands:** send the raw bytes 0xA5 or 0x5A over the USB port.
- **WebSocket** from a browser console:
  ```js
  const ws = new WebSocket('ws://192.168.4.1/ws');
  ws.onmessage = e => console.log(JSON.parse(e.data));
  ws.send(JSON.stringify({cmd: 'start_pump'}));
  ```
- **Display test:** inject a fake `CO2Data` (e.g. waveform 38, RR 16, status2 0) into `displayManager.updateAll()`.
- **PC monitor page parser:** `node tools/tests/test_monitor_parser.js` (§6.4).
- **Firmware:** `test/` is currently empty. Planned unit tests cover the MaCO2 parser (checksum, sync recovery, EtCO₂ peak detection) and the output formatters.
- **End-to-end USB check** used during development: read COM3 for 20 s and confirm that every frame is 24 bytes starting with ESC, with no bytes outside frames.

### 11.2 Troubleshooting

| Symptom | Cause / check |
|---|---|
| Display white/black | Build flags from §10.1 missing; stale build after editing `TFT_eSPI_Setup.h` (`pio run -t clean`); GPIO15 not driven high |
| No diagnostics on the serial monitor | Expected in Legacy format. Press BOOT (ASCII) or build with `-DDEBUG_LOG_ALWAYS=1`. |
| `'AsyncWebServer' does not name a type` | AsyncTCP missing; ESP32 core too old; wrong board |
| ArduinoJson errors | API differences between v6 and v7. The project uses **v7** (`doc["x"].is<T>()`, `JsonDocument`). Include `<ArduinoJson.h>` with that exact case. |
| Boot loop, `abort()` in `check_adc_oneshot_driver_conflict` | Legacy ADC API (`esp_adc_cal.h` / `driver/adc.h`) linked somewhere. Use only `analogRead()` and `esp_adc/adc_cali*.h`. |
| MaCO2 not initializing | TX/RX swapped? Level shifter? +12 V to the sensor? Firmware continues and resyncs anyway. |
| Frequent `# Checksum error` / sync lost | Noise or level-shifter problem, baud mismatch, ground loop |
| ADC values wrong | Dividers (5 V sensors), calibration constants, raw values via `printStatus()` |
| WiFi AP missing | Board stuck in boot mode (GPIO0 held at reset); check serial log |
| LabVIEW gets no data | Charge-only cable; wrong COM port; port held by another program (PIO monitor, the PC monitor page); `setOutputEnabled(true)`; no valid sensor data (output is sent only when `valid`) |
| `pio run -t upload` fails: "could not open port … Access denied" | Another program holds COM3 (PC monitor page, LabVIEW, serial monitor). Disconnect it, then upload. |
| Web page has no Download button after flashing | Browser cache: reload with Ctrl+F5 |
| Moisture / invalid readings | Water trap saturated; cannula or sample line |

---

## 12. Future enhancements

Merged from all earlier roadmaps:
- Persist settings (format, calibration, WiFi, alarm limits, brightness, sweep speed, mmHg/kPa) in NVS/Preferences.
- Web-based calibration page (O₂ two-point, volume scale/offset).
- WiFi station mode or configuration portal.
- On-device alarms with thresholds (EtCO₂/RR high and low, no CO₂ detected, pump stopped), shown on the LCD and web page.
- On-device logging (SD card or flash) for recordings without a connected PC. Long recordings over USB are already possible with the PC monitor page (§6.4). `DataLogger::enableCSVLogging` is a stub.
- MQTT or export to hospital systems. Cloud logging and trend analysis.
- BLE or native mobile app. Multi-sensor or multi-patient support.
- Battery (18650) power with monitoring.
- Unit tests in `test/`.

---

## 13. Superseded design decisions and corrections

Statements from the earlier documents that no longer match the firmware. They're kept here so nobody reintroduces them by mistake.

| Earlier statement | Current reality |
|---|---|
| MaCO2 UART on GPIO 43 (TX) / 44 (RX) | **GPIO 17 (TX) / 18 (RX)** |
| TFT on SPI (MOSI 19, SCLK 18, CS 5, DC 16, RST 23) | T-Display S3 uses an **8-bit parallel bus** (Setup206). Those SPI pins are from the original T-Display; GPIO18 is now UART RX. |
| RGB LED on GPIO 48 | Not present or used on this board |
| SSID `MedAir_Monitor`, password `co2monitor` | **`EAGLEHAGEN`, open (no password)** |
| O₂ calibration `(0.0, 3.3)` | **`(0.0, 1.0)`**, matching the PM1111E 0–1 V output |
| ADC filter default 10 | Class default 10, **set to 5** in `main.cpp` |
| All tasks at 8 Hz | Acquisition 10 Hz, LCD 20 Hz, web 8 Hz, USB output 10 Hz |
| Packet: d[3] unused, d[4] = FetCO₂, d[5] = FiCO₂, d[6–7] unused, no checksum | d[3] = FiCO₂, d[4] = waveform, d[5] = unreliable EtCO₂ (ignored), **d[7] = checksum** |
| Status2 bit 0: 1 = pump running | **0 = running, 1 = stopped** |
| EtCO₂ read from the sensor | **Computed in firmware** from waveform peaks |
| USB output identical to PIC; "no LabVIEW changes needed" | True again. For a while the firmware sent CO₂ as kPa×10, which LabVIEW (expecting mmHg) read about 33 % high. It now sends mmHg (§4.5). |
| `0xF1` is a "restart pump" command byte | F1 is the LabVIEW function key that sends `0xA5` |
| Debug text interleaved with LabVIEW data | Muted in Legacy mode, `#`-prefixed in ASCII mode (§5.8) |
| Web format selector defaults to Tab-Separated | Synced from the device via `output_format` |
| Web page only at `192.168.4.1` | Also at `eaglehagen.local` (mDNS + DNS) |
| Only the PIC/LabVIEW output format | Two formats (Legacy / tab-separated), switchable by button or web |
| Chart.js from CDN | **Embedded gzip** in flash, served at `/chart.min.js` |
| Web files in `data/` on SPIFFS; `pio run -t uploadfs` | Everything is embedded in firmware. No filesystem. |
| Endpoints `/api/data`, `/api/command`, `/command?cmd=` (GET), `/export?format=csv` | `/data`, `POST /command`, WebSocket commands, client-side export |
| LCD shows EtCO₂, FiCO₂/FCO₂, RR, O₂, Volume | LCD shows **FCO2 (kPa) and O₂** only, plus the `Out:` format line |
| Splash title "Ornhagen" / "MedAir CO2 Monitor" | Splash "Teknosofen"; header "Ornhagen"; web "Örnhagens Monitor" |
| ArduinoJson v6 recommended | **v7** in use |
| TFT_eSPI configured by editing the library's `User_Setup_Select.h` | Project file `include/TFT_eSPI_Setup.h`, force-included via build flags (§10.2) |
| ADC voltage via legacy `esp_adc_cal` | `adc_cali` curve fitting. The legacy API crash-looped the board at boot on Arduino core 3.x (§2.5). |
| For LabVIEW, connect USB-Serial to UART2 | LabVIEW uses the **USB-C CDC port** |
| Long recordings need a separate logging program | The PC monitor page records over USB without a time limit (§6.4) |
| PC monitor page only available as a separate file | Embedded in the firmware and downloadable from the web page (`/monitor.html`) |
| Class names `MedAirParser`, `WaveformBuffer`, `CO2WebServer`, `Config.h` (design phase) | Implemented as `MaCO2Parser`, `DisplayManager` (internal buffer), `WiFiManager`, constants in `main.cpp` |

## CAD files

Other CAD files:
documentation/Mech CAD/EagleHagen_Gas_analyzer.f3z

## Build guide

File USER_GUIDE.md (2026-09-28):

# Eaglehagen CO₂ Monitor — User Guide

This guide explains how to use the monitor day to day. For wiring, firmware and protocol details, see [documentation/DESIGN_REFERENCE.md](documentation/DESIGN_REFERENCE.md).

> **All documentation is public** in the project repository: **https://github.com/Teknosofen/EagleHagen**. There you'll find this guide, the design reference, the printable setup handout (`documentation/Eaglehagen_Basic_Setup.pptx`), the PC monitor page (`tools/`) and the firmware source. The latest versions are always there.

---

## 1. What the device does

The Eaglehagen monitor connects to a **MedAir MaCO2-V3** side-stream CO₂ analyser, an **O₂ sensor** and a **volume sensor**, all built into one enclosure (photos: [outside](documentation/Images/IMG_1770.jpg), [inside](documentation/Images/IMG_1771.jpg)).

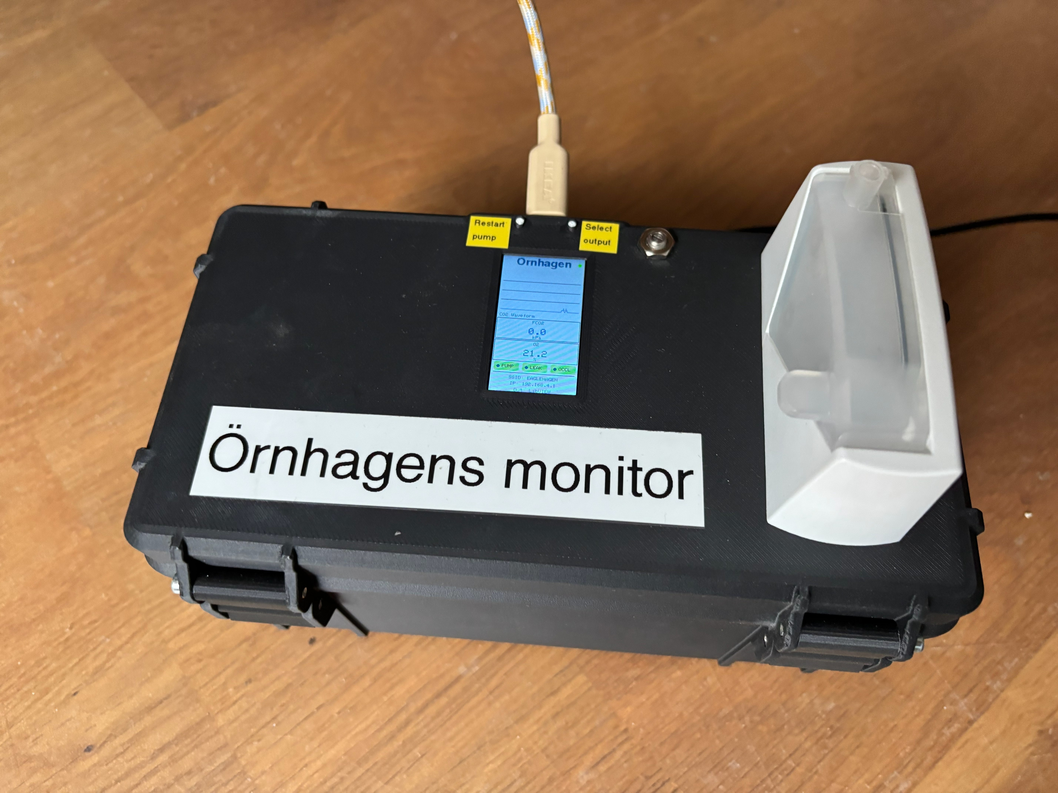
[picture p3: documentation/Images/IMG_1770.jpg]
The Örnhagens monitor: display, Restart pump and Select output buttons, water trap on the right


It shows the readings in three places:

| Where | What you get |
|---|---|
| **Built-in screen** | CO₂ waveform, current CO₂ (kPa), O₂ (%), alarm badges, network info |
| **Phone / tablet / laptop over WiFi** | Live values, three scrolling charts, pump/calibration buttons, data export (CSV/JSON) |
| **PC over USB** | Continuous serial data stream for LabVIEW, the PC monitor page (section 7, downloadable from the device), or any terminal/logging program |

All three can be used at the same time. No internet connection is needed.

---

## 2. Quick start

1. **Connect the sensors** (sample line to the MaCO2, O₂ and volume sensors) and apply **+12 V** power.
2. Wait about 5–15 seconds while the screen shows:
   `Teknosofen – Initializing…` → `Teknosofen – Connecting sensor…` → `Ready! IP: 192.168.4.1` → main screen.
3. On your phone or tablet, join the WiFi network **`EAGLEHAGEN`**. There is **no password**.
4. Open a browser and go to **`http://eaglehagen.local`** (or **`http://192.168.4.1`**, which always works)
5. If the **PUMP** badge is red, press the **Restart pump** button on the device or tap **Start Pump** on the web page.

That's it. The readings update live.

> If the sensor isn't connected at power-up, the device waits up to 10 seconds and then continues anyway. Data starts appearing as soon as the sensor begins sending.

---

## 3. The screen

```
┌──────────────────────────┐
│  Ornhagen          ●WiFi │  Title and WiFi indicator (green = on)
├──────────────────────────┤
│   CO2 waveform plot      │  Scrolling CO₂ curve, auto-scaled
├──────────────────────────┤
│  FCO2      4.3  kPa      │  Current CO₂ value
│  O2       20.9  %        │  Oxygen concentration
├──────────────────────────┤
│ [PUMP] [LEAK] [OCCL]     │  Alarm badges: green = OK, red = problem
│ SSID: EAGLEHAGEN         │  WiFi network to join
│ IP: 192.168.4.1          │  Address to open in the browser
│ Out: LabVIEW             │  Current USB output format
└──────────────────────────┘
```

### Alarm badges

| Badge | Red means | What to do |
|---|---|---|
| **PUMP** | The analyser's sample pump is stopped | Press **Restart pump** on the device or **Start Pump** on the web page |
| **LEAK** | Leak in the sample line | Check the sample line and its connections |
| **OCCL** | Sample line blocked (occlusion) | Check for kinks, water or a saturated water trap. Then restart the pump. |

---

## 4. Physical buttons

The monitor has two push buttons below the display, labelled on the enclosure. See the photo [documentation/Images/IMG_1770.jpg](documentation/Images/IMG_1770.jpg).

| Button | Action |
|---|---|
| **Restart pump** | Sends **Start Pump** to the CO₂ analyser. Use it after an occlusion or whenever the PUMP badge is red. |
| **Select output** | Switches the **USB output format** between **LabVIEW** and **ASCII**. The `Out:` line on the screen shows the current format. |

> ⚠️ Don't hold **Select output** while powering up or resetting the device. It doubles as the board's BOOT button, so holding it puts the board into firmware-download mode and the monitor won't start. If this happens, power-cycle without pressing it.

---

## 5. The web page

Open `http://eaglehagen.local` or `http://192.168.4.1` while connected to `EAGLEHAGEN`. Several devices can be connected at once.

> `eaglehagen.local` works on Windows, Mac, iPhone/iPad, Linux and most Android devices. If a device can't find the name, use `192.168.4.1`, which works everywhere.

**Top bar:**
- **Connected / Connecting…**: link to the device. If the link drops, the page reconnects automatically every 3 seconds.
- **Pump / Leak / Occl** badges: the same meaning as on the device screen. They turn red and pulse on a problem (e.g. `Pump!`).

**Value cards:**

| Card | Meaning | Unit |
|---|---|---|
| End-Tidal CO₂ | Peak CO₂ of the last breath | kPa |
| CO₂ | Current CO₂ value | kPa |
| RR | Respiratory rate | breaths/min |
| O₂ | Oxygen concentration | % |
| Volume | Volume sensor reading | mL |

**Charts:** scrolling plots of CO₂, O₂ and Volume covering the last **2 minutes**.

**Buttons:**

| Button | What it does |
|---|---|
| **Start Pump** | Starts the analyser's sample pump |
| **Zero Calibration** | Zero-calibrates the CO₂ analyser. Only do this with **room air (no breath)** in the sample line. |
| **Save Data (CSV)** | Downloads the recorded data as a spreadsheet file |
| **Save Data (JSON)** | Downloads the same data with metadata (for Python/MATLAB) |
| **Clear Data** | Empties the recording and resets the charts |

**USB Host Output Format:** shows and selects the USB output format. It always reflects the device's current setting, including changes made with the **Select output** button.

**PC monitor page (USB):** the **Download** button at the bottom saves the stand-alone PC monitor page (`Eaglehagen_Serial_Monitor.html`) to the computer you're browsing from. See section 7.

### Recording and exporting data

- **The browser does the recording, not the device.** Recording starts when the page opens and holds the **last 2 minutes** (960 samples). Older samples are dropped.
- The counter under the buttons shows `Data Points: n / 960` and the recording time.
- To capture an event, press **Save** within 2 minutes of it. Keep the page open, because closing or reloading the page loses the data.
- File names look like `medair_co2_data_2026-09-27T10-15-00-000Z.csv`.
- CSV columns: `Timestamp, Elapsed(s), CO2_Waveform(kPa), FetCO2(kPa), FiCO2(kPa), RR(bpm), O2(%), Volume(mL), Pump_Running, Leak_Detected, Occlusion_Detected, Status1, Status2`

For longer recordings, use the PC monitor page over USB (section 7): it records without a time limit.

---

## 6. Connecting a PC (USB)

1. Connect the device's **USB-C** port to the PC. Use a data cable, not a charge-only one.
2. Find the port:
   - **Windows:** Device Manager → *Ports (COM & LPT)* → "USB Serial Device (COMx)" (Swedish Windows: "Seriell USB-enhet")
   - **Linux:** `/dev/ttyACM0`
3. Open the port with **115200 baud, 8 data bits, no parity, 1 stop bit, no flow control**.
4. Data arrives about **10 times per second** whenever the sensor delivers valid data.

### Output formats (toggle with the Select output button or the web page)

**LabVIEW (default at power-up):** the format of the original PIC-based system, a mix of text and binary bytes. It's meant for the existing LabVIEW program.

**ASCII (tab-separated):** plain text that's easy to read in a terminal or import into Excel, Python or MATLAB. Each line:

```
CO2_kPa <TAB> O2_% <TAB> RR <TAB> Volume_mL <TAB> Status1 <TAB> Status2
```
Example: `4.3	20.9	14	320	6	0`

> **Tip:** the PC monitor page (section 7) accepts both formats and detects which one is in use.

> **Diagnostic messages:** in **LabVIEW** format the port carries only data frames. In **ASCII** format the device also sends occasional diagnostic lines, which always start with `#`. A logging program should skip lines starting with `#`.

### Controlling the analyser from the PC

Sending a single byte over the USB port forwards a command to the analyser:

| Byte | Command |
|---|---|
| `0xA5` | Start pump |
| `0x5A` | Zero calibration |

All other bytes are ignored.

---

## 7. PC monitor page (no LabVIEW needed)

`Eaglehagen_Serial_Monitor.html` is a stand-alone page that shows the monitor's data on a PC over the USB cable. It needs no installation and no internet, and nothing is sent anywhere.

The monitor itself carries a copy of the page, so you don't need any other files. You can also find it in this project as [tools/Eaglehagen_Serial_Monitor.html](tools/Eaglehagen_Serial_Monitor.html).

> **Both output formats work.** The page reads the **LabVIEW** format and the **ASCII** format, and detects which one is arriving by itself. You don't need to press **Select output** before using it. If someone presses it while you are connected, the page follows the switch without reconnecting.

### Step 1: Get the page over WiFi (once per PC)

1. On the PC, join the WiFi network **`EAGLEHAGEN`** (no password).
2. Open **`http://eaglehagen.local`** (or `http://192.168.4.1`).
3. At the bottom of the web page, under **PC monitor page (USB)**, click **Download**. Save the file somewhere easy to find, for example the desktop.
4. Switch the PC back to its normal WiFi if you like. The saved page doesn't need any network.

The page can't be used directly from the WiFi address: browsers only allow serial-port access from a saved file. The saved copy keeps working, so this step is needed only once per PC (and again after a firmware update, to get the latest version).

### Step 2: Connect with the USB cable

1. Close LabVIEW, or any other program using the monitor's COM port. Only one program can use a port at a time.
2. Connect the monitor's USB-C port to the PC.
3. Open the saved file in **Google Chrome** or **Microsoft Edge** (right-click → *Open with*, if another browser is the default). Other browsers can't access serial ports; the page tells you if that's the problem.
4. Scroll to the **Serial port** panel at the bottom of the page.
   - **First time only:** click **Add port…** and choose the monitor's COM port in the browser's list. It may be named "USB JTAG/serial debug unit" or "USB Serial Device". The browser requires this one step.
   - After that, the monitor appears in the **Serial port** list and is selected automatically.
5. Leave **Baud rate** at 115200 and **Data format** at *Auto-detect*, then click **Connect selection**.

The status pill at the top right shows **Receiving data** when values are coming in.

### What you see

- **Alarm badges:** Data valid, Pump, Leak and Occlusion. Green means OK; red and pulsing means a problem.
- **Values:** end-tidal CO₂ (kPa, with mmHg underneath), CO₂, respiratory rate, O₂ and volume.
- **Charts:** scrolling CO₂ waveform, O₂ and volume. The time window can be set to 30 s, 1, 2 or 5 minutes.
- **◐ button:** switches between a dark and a light theme.

What differs between the two formats:

| | LabVIEW format | ASCII format |
|---|---|---|
| End-tidal CO₂ | Sent by the monitor | Calculated by the page from the waveform |
| FiCO₂ | Shown under the CO₂ value | Not available |
| Volume | Raw ADC counts (0–1023) | mL |
| Device messages (`#` lines) | None | Shown in the log at the bottom |

### Recording and CSV

- Everything received while connected is recorded, with **no 2-minute limit**. **Pause** stops recording temporarily and **Clear** starts over.
- **Save CSV** stores the recording. Chrome and Edge let you choose where to save it.
- **CSV style:** choose *Swedish Excel* if the file will be opened in Excel with Swedish settings (it then uses `;` and decimal commas).
- The columns are the same as the web page export, plus `Volume(ADC)` and `Format`. CO₂ values are in kPa.

### Other controls

- **Start pump** and **Zero calibration** work as on the web page. Zero calibration asks for confirmation; use it only with room air.
- **Device messages & connection log** at the bottom lists connections, format changes and device messages.
- To try the page without a device, add `#demo` to the end of the address in the browser.

---

## 8. Units and normal values

- All CO₂ values are shown in **kPa** (1 kPa ≈ 7.5 mmHg).
- Typical end-tidal CO₂ in a healthy adult is about **4.5–6.0 kPa** (35–45 mmHg).
- Inspired CO₂ should be close to **0**. Raised values suggest rebreathing.
- Room air O₂ is about **20.9 %**.
- The End-Tidal CO₂ value is computed by the monitor from the waveform peak of each breath. It shows `0` until the first breath has been detected.

---

## 9. Troubleshooting

| Problem | Check |
|---|---|
| Screen stays dark | Power supply (+12 V) and the USB-C/5 V feed to the board |
| Stuck on "Connecting sensor…" | It continues after 10 s. If no values appear, check the MaCO2's power and serial cable. |
| No CO₂ values / flat line | Sample line connected? PUMP badge green? Try **Start Pump**. |
| CO₂ reads high with no breath | Run **Zero Calibration** with room air in the sample line |
| OCCL badge red | Kinked or wet sample line or full water trap. Fix, then **Start Pump**. |
| LEAK badge red | Loose connector or damaged sample line |
| Can't find the `EAGLEHAGEN` network | Wait until the main screen appears. Move closer. Power-cycle the device. |
| No **Download** button on the web page | Reload with Ctrl+F5 (the browser may show an old cached page). The button needs the current firmware. |
| Web page won't load | Make sure the phone is on `EAGLEHAGEN` (some phones switch back to mobile data when a WiFi has no internet — allow staying connected). Use `http://`, not `https://`. |
| `eaglehagen.local` not found | Use `http://192.168.4.1` instead. Some Android devices and VPN apps don't resolve `.local` names. |
| Page shows "Connecting…" | The device restarted or is out of range. The page reconnects by itself. |
| PC receives no data | Data-capable USB cable? Correct COM port? No other program (e.g. a serial monitor) holding the port? |
| LabVIEW gets garbled data | The format may be set to ASCII. Press **Select output** until the screen shows `Out: LabVIEW`. |
| PC monitor page can't connect | Close LabVIEW or other programs using the COM port. Use Chrome or Edge. |
| PC monitor page says the browser can't open serial ports | You opened it from the WiFi address, or in another browser. Download it, then open the saved file in Chrome or Edge. |
| Device doesn't start after pressing Select output | It was held during power-up and started in download mode. Power-cycle without holding it. |

---

## 10. Quick reference

| | |
|---|---|
| WiFi network | `EAGLEHAGEN` (no password) |
| Web address | `http://eaglehagen.local` or `http://192.168.4.1` |
| USB serial | 115200 8N1, ~10 lines/s |
| Restart pump button | Starts the sample pump |
| Select output button | Toggles USB format LabVIEW ⇄ ASCII |
| Web recording | Last 2 minutes, export CSV/JSON |
| Commands over USB | `0xA5` start pump, `0x5A` zero cal |
| PC monitor page | Download from the web page (WiFi), then open the file in Chrome/Edge; both formats |
| Documentation | https://github.com/Teknosofen/EagleHagen |

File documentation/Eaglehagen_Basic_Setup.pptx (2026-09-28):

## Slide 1

Eaglehagen CO₂ Monitor

Basic setup

A short guide to getting started with the monitor:
screen, web page, alarms, LabVIEW and the PC monitor page.

Ornhagen

CO2 Waveform

SSID: EAGLEHAGEN

IP: 192.168.4.1

Out: LabVIEW

4.3

20.9

FCO2

O2

PUMP

kPa

%

OCCL

Prepared for Dr. Örnhagen · September 2026

All documentation: github.com/Teknosofen/EagleHagen

LEAK

by Teknosofen

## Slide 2

Getting started in four steps

From power-on to live values on your phone or tablet

Connect

Attach the sample line, O₂ and volume sensors. Switch on the +12 V supply.

Web address

Wait ~15 s

The screen shows “Initializing”, “Connecting sensor”, then “Ready!” and the main screen.

Join WiFi

On the phone or tablet, join the network EAGLEHAGEN. There is no password.

Open the page

In the browser, go to the web address shown below.

1

2

3

4

›

›

›

http://eaglehagen.local or http://192.168.4.1

Tip: if the PUMP badge is red, press the Restart pump button on the device, or tap Start Pump on the web page.

by Teknosofen

· Eaglehagen CO₂ Monitor · Basic setup

2

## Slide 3

Reading the device screen

Everything important is visible without a phone or PC

Ornhagen

CO2 Waveform

SSID: EAGLEHAGEN

IP: 192.168.4.1

Out: LabVIEW

4.3

20.9

1

Title and WiFi Green dot: the WiFi network is on.

2

CO₂ waveform Scrolling curve of every breath, scaled automatically.

FCO2

kPa

3

FCO2 Current CO₂ value in kPa.

O2

PUMP

%

OCCL

4

O₂ Oxygen concentration in %.

LEAK

5

Alarm badges Green = OK, red = problem. See next page.

6

Network and output WiFi name, web address and the USB format (“Out:”).

by Teknosofen

· Eaglehagen CO₂ Monitor · Basic setup

3

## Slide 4

Buttons and alarms

Two labelled buttons next to the display, three alarm badges on the screen and web page

Buttons

Restart pump

Starts the sample pump. Use it when the PUMP badge is red.

Alarm badges

Sample pump stopped

Press Restart pump on the device or Start Pump on the web page.

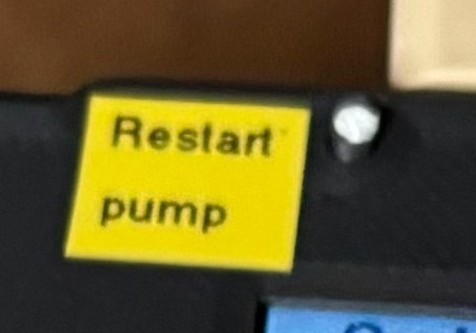
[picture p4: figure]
Photo of the Restart pump button

PUMP

Select output

Switches the USB output between LabVIEW and ASCII (see “Out:”).

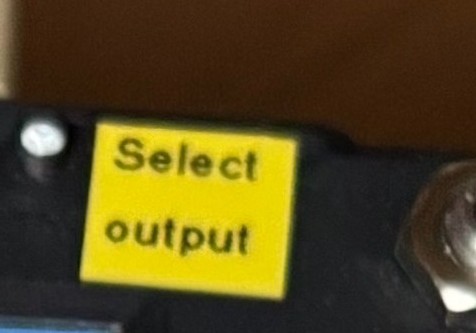
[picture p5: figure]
Photo of the Select output button

Leak in the sample line

Check the sample line and its connectors.

LEAK

Caution: do not hold Select output while switching the device on. It then starts in programming mode and the monitor will not run. Just switch off and on again.

Sample line blocked

Check for kinks, water or a full water trap. Then restart the pump.

All green means the analyser is sampling normally.

OCCL

by Teknosofen

· Eaglehagen CO₂ Monitor · Basic setup

4

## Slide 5

The web page

Live values, charts, pump control and data export on any phone, tablet or laptop

eaglehagen.local

Örnhagens Monitor

Start Pump

Starts the analyser’s sample pump.

Connected

Pump

Leak

Occl

EtCO₂

5.3

CO₂

4.1

RR

14

O₂

20.9

Vol

320

CO₂ (kPa)

Zero Calibration

Zeroes the CO₂ reading. Only with room air in the sample line, never with breath.

Save CSV / JSON

Downloads the recorded data (spreadsheet, or for Python/MATLAB).

O₂ (%)

Clear Data

Empties the recording and resets the charts.

Volume (mL)

Recording lives in the browser
The page keeps the last 2 minutes: save soon after an event and keep the page open. For longer recordings, use the PC monitor page (page 7).

Start Pump

Zero Cal

Save CSV

Save JSON

Clear

by Teknosofen

· Eaglehagen CO₂ Monitor · Basic setup

5

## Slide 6

Connecting the LabVIEW PC

The existing LabVIEW program works unchanged, over one USB-C cable

Monitor

Screen shows
“Out: LabVIEW”

PC

COM port
115200 baud, 8N1

LabVIEW

Your program,
no changes

USB-C

VISA

1

Connect the monitor’s USB-C port to the PC. Use a data cable, not a charge-only cable.

2

Check that the screen shows “Out: LabVIEW”. If it shows “Out: ASCII”, press the Select output button once.

3

In LabVIEW, select the monitor’s COM port (Windows Device Manager → Ports: “USB Serial Device”).

4

F1 (restart pump) and F2 (zero CO₂) work as before. The web page can be used at the same time.

ASCII format: plain text lines (CO₂ kPa, O₂ %, RR, volume, status) for Excel, Python or a terminal. Lines starting with # are messages and can be skipped. No LabVIEW? See the next page.

by Teknosofen

· Eaglehagen CO₂ Monitor · Basic setup

6

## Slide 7

Monitoring on a PC without LabVIEW

A ready-made page for Chrome or Edge: live values, charts and CSV recording over USB

The monitor page, light theme

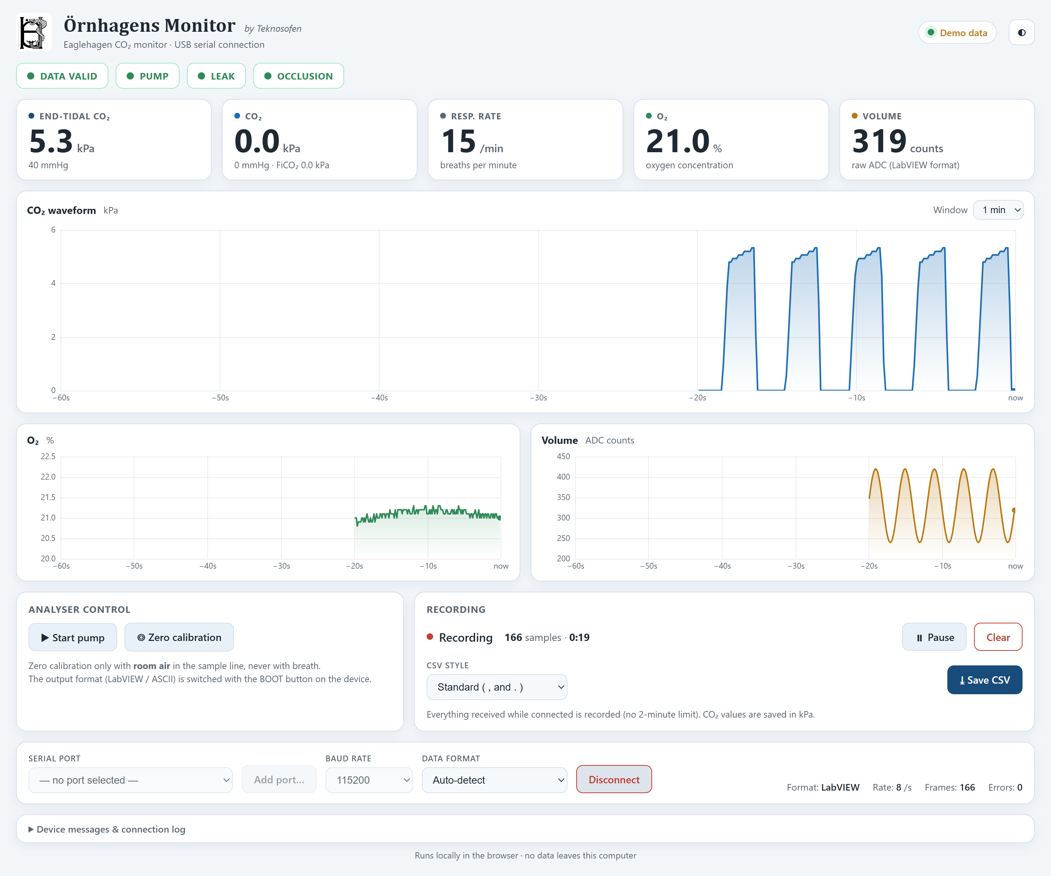
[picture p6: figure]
Screenshot of the PC monitor page

Accepts both output formats
LabVIEW and ASCII are detected automatically, even if Select output is pressed while connected.

1

Download it over WiFi (once)

Join EAGLEHAGEN, open eaglehagen.local and click “Download” at the bottom.

2

Plug in the USB cable

Close LabVIEW first: only one program can use the COM port.

3

Open the saved file

In Chrome or Edge. First time: “Add port…” and choose the monitor.

4

Connect and record

Click “Connect selection”. Everything is recorded; “Save CSV” stores it.

The monitor carries its own copy of this page, so no other files are needed. Start pump and Zero calibration work here too.

by Teknosofen

· Eaglehagen CO₂ Monitor · Basic setup

7

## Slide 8

If something is wrong

The most common situations and what to do

Problem | What to do
Screen stays dark | Check the +12 V supply and the power lead to the board.
Stuck on “Connecting sensor” | It continues after 10 s. If no values appear, check the analyser’s power and serial cable.
Flat CO₂ line, no values | Is the sample line connected and the PUMP badge green? Try Start Pump.
CO₂ reads high with no breath | Run Zero Calibration with room air in the sample line.
OCCL or LEAK badge red | Kinked, wet or loose sample line, or a full water trap. Fix, then Start Pump.
EAGLEHAGEN network missing | Wait for the main screen, move closer, or switch the device off and on.
Web page does not load | Is the phone still on EAGLEHAGEN? Allow it to stay on a network without internet. Try http://192.168.4.1.
LabVIEW gets no or garbled data | Data-capable USB cable? Correct COM port? Screen must show “Out: LabVIEW”.
PC monitor page cannot connect | Close LabVIEW (only one program per port). Use Chrome or Edge.

by Teknosofen

· Eaglehagen CO₂ Monitor · Basic setup

8

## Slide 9

Quick reference

Keep this page next to the monitor

WiFi network

EAGLEHAGEN

no password

Web address

eaglehagen.local

or 192.168.4.1

Button

Restart pump

starts the sample pump

Button

Select output

USB format LabVIEW ⇄ ASCII

Normal EtCO₂

4.5–6.0 kPa

≈ 35–45 mmHg, adult

Room air O₂

20.9 %

reference check

USB serial

115200 8N1

~10 frames per second

Web recording

2 minutes

longer: PC monitor page

Documentation, latest versions and the PC monitor page: https://github.com/Teknosofen/EagleHagen

by Teknosofen

· Eaglehagen CO₂ Monitor · Basic setup

9

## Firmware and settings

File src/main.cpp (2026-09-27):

// main.cpp
// Main application for ESP32 MedAir CO2 Monitor
// Coordinates all subsystems and manages data flow

#include <Arduino.h>
#include "MaCO2Parser.h"
#include "ADCManager.h"
#include "DisplayManager.h"
#include "WiFiManager.h"
#include "DataLogger.h"
#include "Button.hpp"
#include "DebugLog.h"

// ============================================================================
// Configuration
// ============================================================================

// WiFi Settings
const char* WIFI_SSID = "EAGLEHAGEN";
const char* WIFI_PASSWORD = ""; // no password "co2monitor";
const bool WIFI_AP_MODE = true;  // true = Access Point, false = Station
const char* HOSTNAME = "eaglehagen";  // Web page also reachable as http://eaglehagen.local

// Pin Definitions
#define UART_RX_MACO2   18  // U1_RXD - Dedicated UART1 RX pin
#define UART_TX_MACO2   17  // U1_TXD - Dedicated UART1 TX pin
#define O2_SENSOR_PIN   1
#define VOL_SENSOR_PIN  2
#define BUTTON_PIN      14  // IO14 - Pump start button
#define BOOT0_PIN        0  // GPIO0 - Format toggle button

// Update intervals
#define DATA_UPDATE_INTERVAL_MS     100   // 10Hz data acquisition (faster than sensor's 8Hz to prevent buffer buildup)
#define DISPLAY_UPDATE_INTERVAL_MS  50    // 20Hz display refresh
#define WIFI_UPDATE_INTERVAL_MS     125   // 8Hz web update (match sensor nominal rate)
#define LABVIEW_UPDATE_INTERVAL_MS  200   // 5Hz LabVIEW output (reduced to prevent timing issues)

// ============================================================================
// Global Objects
// ============================================================================

HardwareSerial SerialMaCO2(1);  // UART1 for MaCO2 sensor

MaCO2Parser maco2Parser;
ADCManager adcManager(O2_SENSOR_PIN, VOL_SENSOR_PIN);
DisplayManager displayManager;
WiFiManager wifiManager;
DataLogger dataLogger;
Button pumpButton(BUTTON_PIN, 1000, 50);  // IO14, 1000ms long press, 50ms debounce
Button formatButton(BOOT0_PIN, 1000, 50); // GPIO0 (BOOT0), format toggle

CO2Data currentData;

// Timing variables
unsigned long lastDataUpdate = 0;
unsigned long lastDisplayUpdate = 0;
unsigned long lastWiFiUpdate = 0;
unsigned long lastLabViewUpdate = 0;

// ============================================================================
// Setup
// ============================================================================

void setup() {
    // Initialize USB CDC serial for debugging and LabVIEW
    Serial.begin(115200);
    delay(1000);
    
    DebugOut.println("\n=================================");
    DebugOut.println("MedAir CO2 Monitor - ESP32");
    DebugOut.println("=================================\n");
    
    // Initialize Display
    DebugOut.println("Initializing display...");
    if (!displayManager.begin()) {
        DebugOut.println("ERROR: Display initialization failed!");
        while(1) delay(1000);
    }
    displayManager.showSplash("Teknosofen", "Initializing...");
    delay(1000);
    
    // Initialize ADC Manager
    DebugOut.println("Initializing ADC...");
    
    // Configure volume sensor pin with weak pull-down
    pinMode(VOL_SENSOR_PIN, INPUT);
    gpio_pulldown_en((gpio_num_t)VOL_SENSOR_PIN);
    gpio_pullup_dis((gpio_num_t)VOL_SENSOR_PIN);
    
    if (!adcManager.begin()) {
        DebugOut.println("ERROR: ADC initialization failed!");
        while(1) delay(1000);
    }
    
    // Set ADC filter size (moving average)
    adcManager.setFilterSize(5);
    
    // Set ADC calibration (adjust these for your sensors)
    // O2 sensor: 0V = 0%, 1V = 100% (0-1V input range)
    adcManager.setO2Calibration(0.0, 1.0);
    
    // Volume sensor: 200 mL per volt (example value)
    adcManager.setVolumeCalibration(200.0, 0.0);
    
    // Initialize MaCO2 communication
    DebugOut.println("Initializing MaCO2 communication...");
    displayManager.showSplash("Teknosofen", "Connecting sensor...");
    SerialMaCO2.begin(9600, SERIAL_8N1, UART_RX_MACO2, UART_TX_MACO2);
    
    if (!maco2Parser.initialize(SerialMaCO2, 10000)) {
        DebugOut.println("WARNING: MaCO2 initialization timeout");
        DebugOut.println("Continuing anyway - sensor may connect later");
        delay(1000);
    }
    
    // Initialize WiFi
    DebugOut.println("Initializing WiFi...");
    if (WIFI_AP_MODE) {
        if (wifiManager.beginAP(WIFI_SSID, WIFI_PASSWORD)) {
            DebugOut.printf("AP Mode: SSID='%s', IP=%s\n", 
                         WIFI_SSID, wifiManager.getIP().toString().c_str());
        } else {
            DebugOut.println("WARNING: WiFi AP failed to start");
        }
    }
    
    // Start web server
    if (wifiManager.startServer()) {
        DebugOut.println("Web server started");
    } else {
        DebugOut.println("WARNING: Web server failed to start");
    }
    wifiManager.beginHostname(HOSTNAME);

    // Initialize Data Logger
    dataLogger.begin();
    
    // Link DataLogger to WiFiManager (for format control)
    wifiManager.setDataLogger(&dataLogger);
    dataLogger.setOutputEnabled(true);  // Enable host output via USB CDC
    
    // Initialize Buttons
    DebugOut.println("Initializing buttons...");
    pumpButton.begin();
    formatButton.begin();
    DebugOut.println("IO14: pump start | BOOT0: toggle output format");
    
    // Show ready screen with IP
    char ipStr[32];
    snprintf(ipStr, sizeof(ipStr), "IP: %s", wifiManager.getIP().toString().c_str());
    displayManager.showSplash("Ready!", ipStr);
    delay(1000);
    
    // Clear screen and set network info for status display
    displayManager.clearScreen();
    displayManager.setNetworkInfo(WIFI_SSID, wifiManager.getIP().toString().c_str());
    displayManager.setOutputFormatName(dataLogger.getOutputFormat() == FORMAT_LEGACY_LABVIEW ? "Out: LabVIEW" : "Out: ASCII");
    
    DebugOut.println("\n=== System Ready ===");
    DebugOut.println("USB CDC: host data output enabled");
    DebugOut.printf("WiFi: Connect to '%s' and open http://%s or http://%s.local\n",
                  WIFI_SSID, wifiManager.getIP().toString().c_str(), HOSTNAME);
    DebugOut.println("====================\n");
    
    // Initialize current data structure
    memset(&currentData, 0, sizeof(currentData));
}

// ============================================================================
// Main Loop
// ============================================================================

void loop() {
    unsigned long now = millis();
    
    // -------------------------------------------------------------------------
    // Data Acquisition (10Hz - faster than sensor to prevent buffer buildup)
    // -------------------------------------------------------------------------
    if (now - lastDataUpdate >= DATA_UPDATE_INTERVAL_MS) {
        lastDataUpdate = now;

        // Parse MaCO2 data (non-blocking)
        if (maco2Parser.parsePacket(SerialMaCO2, currentData)) {
            // Got new data from sensor
            
            // Update ADC readings
            adcManager.update(currentData);
            
            // Add waveform point to display buffer
            displayManager.addWaveformPoint(currentData.co2_waveform);
        }
    }
    
    // -------------------------------------------------------------------------
    // Display Update (20Hz)
    // -------------------------------------------------------------------------
    if (now - lastDisplayUpdate >= DISPLAY_UPDATE_INTERVAL_MS) {
        lastDisplayUpdate = now;
        displayManager.updateAll(currentData);
    }
    
    // -------------------------------------------------------------------------
    // WiFi/Web Update (8Hz)
    // -------------------------------------------------------------------------
    if (now - lastWiFiUpdate >= WIFI_UPDATE_INTERVAL_MS) {
        lastWiFiUpdate = now;
        wifiManager.update(currentData);
    }
    
    // -------------------------------------------------------------------------
    // Host Output (10Hz) - Legacy LabVIEW or Tab-Separated format
    // -------------------------------------------------------------------------
    if (now - lastLabViewUpdate >= DATA_UPDATE_INTERVAL_MS) {  // 10Hz, same as data acquisition
        lastLabViewUpdate = now;

        if (currentData.valid) {
            dataLogger.sendData(Serial, currentData);
        }
    }
    
    // -------------------------------------------------------------------------
    // Handle Commands
    // -------------------------------------------------------------------------
    
    // Handle pump button press
    pumpButton.update();
    if (pumpButton.wasPressed()) {
        DebugOut.println("Button pressed - sending pump start command");
        maco2Parser.sendCommand(SerialMaCO2, CMD_START_PUMP);
    }

    // Handle format toggle button (BOOT0)
    formatButton.update();
    if (formatButton.wasPressed()) {
        OutputFormat newFormat = (dataLogger.getOutputFormat() == FORMAT_LEGACY_LABVIEW)
                                 ? FORMAT_TAB_SEPARATED : FORMAT_LEGACY_LABVIEW;
        dataLogger.setOutputFormat(newFormat);
        const char* formatName = (newFormat == FORMAT_LEGACY_LABVIEW) ? "Out: LabVIEW" : "Out: ASCII";
        displayManager.setOutputFormatName(formatName);
        DebugOut.printf("Output format switched to: %s\n", formatName);
    }
    
    // Commands from web interface
    if (wifiManager.hasCommand()) {
        uint8_t cmd = wifiManager.getCommand();
        maco2Parser.sendCommand(SerialMaCO2, (MaCO2Command)cmd);
    }
    
    // Commands from LabVIEW via USB CDC
    if (Serial.available()) {
        uint8_t cmd = Serial.read();
        if (cmd == CMD_START_PUMP || cmd == CMD_ZERO_CAL) {
            maco2Parser.sendCommand(SerialMaCO2, (MaCO2Command)cmd);
        }
    }
    
    // WiFi manager loop (handles WebSocket events)
    wifiManager.loop();
    
    // Small delay to prevent watchdog issues
    // delay(1);
}

// ============================================================================
// Helper Functions
// ============================================================================

void printStatus() {
    DebugOut.println("\n=== System Status ===");
    DebugOut.printf("MaCO2 Packets: %lu (errors: %lu)\n", 
                  maco2Parser.getPacketCount(), 
                  maco2Parser.getErrorCount());
    DebugOut.printf("LabVIEW Packets: %lu (%lu bytes)\n",
                  dataLogger.getPacketsSent(),
                  dataLogger.getBytesSent());
    DebugOut.printf("WiFi Clients: %d\n", wifiManager.getClientCount());
    DebugOut.printf("O2: %.1f%% (raw: %d, %.3fV)\n",
                  currentData.o2_percent,
                  adcManager.getO2Raw(),
                  adcManager.getO2Voltage());
    DebugOut.printf("Vol: %.1f mL (raw: %d, %.3fV)\n",
                  currentData.volume_ml,
                  adcManager.getVolRaw(),
                  adcManager.getVolVoltage());
    DebugOut.printf("CO2: FetCO2=%d, FCO2=%d, RR=%d\n",
                  currentData.fetco2,
                  currentData.fco2,
                  currentData.respiratory_rate);
    DebugOut.printf("Status: Pump=%s, Leak=%s, Occlusion=%s\n",
                  maco2Parser.isPumpRunning(currentData) ? "ON" : "OFF",
                  maco2Parser.isLeakDetected(currentData) ? "YES" : "NO",
                  maco2Parser.isOcclusionDetected(currentData) ? "YES" : "NO");
    DebugOut.println("====================\n");
}

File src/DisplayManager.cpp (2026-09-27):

// DisplayManager.cpp
// Implementation of TFT display management for LilyGO T-Display S3

#include "DisplayManager.h"
#include "DebugLog.h"

// Layout constants for status section
static const uint8_t STATUS_SEPARATOR_Y = 24;
static const uint8_t SSID_Y_OFFSET = 35;
static const uint8_t IP_Y_OFFSET = 48;

DisplayManager::DisplayManager()
    : _waveformIndex(0)
    , _waveformMin(0)
    , _waveformMax(100)
    , _lastUpdateTime(0)
    , _refreshRate(50)
    , _waveformSpeed(2)
    , _backlightBrightness(200)
{
    memset(_waveformBuffer, 0, sizeof(_waveformBuffer));
    
    // Initialize network info
    memset(_ssid, 0, sizeof(_ssid));
    memset(_ip, 0, sizeof(_ip));

    // Initialize output format label
    memset(_outputFormatName, 0, sizeof(_outputFormatName));
    memset(_prevFormatName, 0, sizeof(_prevFormatName));
    
    // Initialize previous values
    _prevValues.co2_waveform = 255;
    _prevValues.fco2 = 255;
    _prevValues.o2_percent = -1;
    _prevValues.volume_ml = -1;
    _prevValues.status2 = 255;
    memset(_prevValues.fco2_wave_str, 0, sizeof(_prevValues.fco2_wave_str));
    memset(_prevValues.fco2_str, 0, sizeof(_prevValues.fco2_str));
    memset(_prevValues.o2_str, 0, sizeof(_prevValues.o2_str));
    memset(_prevValues.vol_str, 0, sizeof(_prevValues.vol_str));
    
    // Initialize previous title
    memset(_prevTitle, 0, sizeof(_prevTitle));
    
    // Define layout zones (portrait orientation: 170x320)
    _layout.header_y = 0;
    _layout.header_h = 30;  // Header section height
    
    _layout.wave_y = 30;  // Waveform starts after header
    _layout.wave_h = 120;  // Compacted to make room for format note at bottom

    _layout.values_y = 150;
    _layout.values_h = 100;

    _layout.status_y = 250;
    _layout.status_h = 70;  // Extended to fit format note below IP
}

bool DisplayManager::begin() {
    DebugOut.println("Initializing TFT display...");
    
    // Enable display power (GPIO 15 controls display power on T-Display S3)
    pinMode(15, OUTPUT);
    digitalWrite(15, HIGH);
    delay(100);  // Wait for power to stabilize
    
    _tft.init();
    _tft.setRotation(2);  // Portrait mode (180° rotated)
    _tft.fillScreen(TFT_BLACK);
    
    // Set backlight
    pinMode(TFT_BL, OUTPUT);
    digitalWrite(TFT_BL, HIGH);  // Turn on immediately
    setBacklight(_backlightBrightness);
    
    DebugOut.println("TFT display initialized");
    return true;
}

void DisplayManager::showSplash(const char* title, const char* subtitle) {
    _tft.fillScreen(TFT_LOGOBACKGROUND);
    _tft.setTextColor(TFT_DARKERBLUE, TFT_LOGOBACKGROUND);
    _tft.setTextDatum(MC_DATUM);
    
    // Title with FreeSans font for better appearance
    _tft.setFreeFont(&FreeSansBold12pt7b);
    _tft.drawString(title, SCREEN_WIDTH / 2, SCREEN_HEIGHT / 2 - 10);
    _tft.setTextFont(1);
    
    // Subtitle in lighter color
    if (subtitle) {
        _tft.setTextColor(TFT_SLATEBLUE, TFT_LOGOBACKGROUND);
        _tft.setTextSize(1);
        _tft.drawString(subtitle, SCREEN_WIDTH / 2, SCREEN_HEIGHT / 2 + 20);
    }
}

void DisplayManager::clearScreen() {
    _tft.fillScreen(TFT_LOGOBACKGROUND);
}

void DisplayManager::setNetworkInfo(const char* ssid, const char* ip) {
    if (ssid) {
        strncpy(_ssid, ssid, sizeof(_ssid) - 1);
        _ssid[sizeof(_ssid) - 1] = '\0';
    }
    if (ip) {
        strncpy(_ip, ip, sizeof(_ip) - 1);
        _ip[sizeof(_ip) - 1] = '\0';
    }
}

void DisplayManager::setOutputFormatName(const char* name) {
    if (name) {
        strncpy(_outputFormatName, name, sizeof(_outputFormatName) - 1);
        _outputFormatName[sizeof(_outputFormatName) - 1] = '\0';
    }
}

void DisplayManager::updateAll(const CO2Data& data) {
    // Throttle updates based on refresh rate
    if (millis() - _lastUpdateTime < _refreshRate) {
        return;
    }
    _lastUpdateTime = millis();
    
    // Draw all sections (header only redraws if title changed)
    drawHeader("Ornhagen");
    updateWaveform(data);
    updateNumericValues(data);
    updateStatusIndicators(data);
}

void DisplayManager::updateWaveform(const CO2Data& data) {
    // Clear waveform area completely each time
    _tft.fillRect(0, _layout.wave_y, SCREEN_WIDTH, _layout.wave_h, TFT_LOGOBACKGROUND);
    
    // Draw label
    _tft.setTextColor(TFT_SLATEBLUE, TFT_LOGOBACKGROUND);
    _tft.setTextDatum(BL_DATUM);
    _tft.setTextSize(1);
    _tft.drawString("CO2 Waveform", 5, _layout.wave_y + _layout.wave_h - 2);
    
    // Draw waveform
    plotWaveform();
}

void DisplayManager::updateNumericValues(const CO2Data& data) {
    const uint16_t y_start = _layout.values_y;
    const uint16_t _width = SCREEN_WIDTH;  // Full width for both boxes

    // Create temporary char buffers for string conversion
    char fco2_wave_str[8];
    char fco2_str[8];
    char o2_str[8];

    // Convert CO2 values from mmHg to kPa (1 mmHg = 0.133322 kPa)
    // FINAL CORRECTED mapping based on actual sensor data analysis:
    // d[3] = FiCO2 - Inspired CO2 baseline (~0-3 mmHg) - stored in data.fco2
    // d[4] = FCO2 - Real-time 8Hz CO2 waveform (0-32 mmHg) - stored in data.co2_waveform
    // d[5] = FetCO2 - End-tidal peak value (0-120 mmHg) - stored in data.fetco2

    float fco2_waveform_kpa = (float)data.co2_waveform * 0.133322;  // d[4] - Real-time curve

    // Convert values to strings with one decimal place for CO2
    snprintf(fco2_wave_str, sizeof(fco2_wave_str), "%.1f", fco2_waveform_kpa);  // FCO2 waveform
    snprintf(o2_str, sizeof(o2_str), "%.1f", data.o2_percent);

    // First row: FCO2 (8Hz waveform) - FULL WIDTH
    // FCO2 box shows real-time breathing curve (updates every 125ms at 8Hz)
    if (data.co2_waveform != _prevValues.co2_waveform) {
        drawMetricBox(0, y_start, _width, 50,
                      "FCO2", _prevValues.fco2_wave_str, (const char*)fco2_wave_str, "kPa",
                      TFT_DARKERBLUE);
        _prevValues.co2_waveform = data.co2_waveform;
        strncpy(_prevValues.fco2_wave_str, fco2_wave_str, sizeof(_prevValues.fco2_wave_str));
    }

    // Second row: O2 - FULL WIDTH
    if (abs(data.o2_percent - _prevValues.o2_percent) > 0.05) {  // Update if changed by > 0.05%
        drawMetricBox(0, y_start + 50, _width, 50,
                      "O2", _prevValues.o2_str, (const char*)o2_str, "%",
                      TFT_SLATEBLUE);  // Slate blue for O2
        _prevValues.o2_percent = data.o2_percent;
        strncpy(_prevValues.o2_str, o2_str, sizeof(_prevValues.o2_str));
    }
}
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

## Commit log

2026-01-06 Improved LCD display and fixed CO2 presentation bug
    [DisplayManager.cpp, main.cpp]
2026-01-06 Added button handler to allow pump restart without using web or host interface
2026-01-06 improved GUI on WEB and LCD, fixed MACO2 parsing issues
    [DisplayManager.cpp, MaCO2Parser.cpp]
2026-02-01 now not depending on LS from external source, added button control of output format
2026-09-27 Fix boot loop, clean LabVIEW output, add eaglehagen.local, pin versions
    - ADC: replace legacy esp_adc_cal with adc_cali curve fitting; the legacy
    API aborted at boot on Arduino core 3.x (ADC driver conflict)
    - LabVIEW format: send CO2 (and FiCO2/EtCO2) in mmHg as the PIC did, so
    the existing LabVIEW program works unchanged
    - Route all diagnostics through DebugOut: muted in LabVIEW format,
    '#'-prefixed in ASCII format; disable Arduino-core logging
    - Web page reads the actual output format from each WebSocket frame
    - Serve the web page as http://eaglehagen.local (mDNS + AP DNS answer)
    - TFT_eSPI setup moved into the project (include/TFT_eSPI_Setup.h),
    no library edits needed
    - Pin plat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
    [ADCManager.cpp, DisplayManager.cpp, MaCO2Parser.cpp]
2026-09-27 Consolidate documentation, add user guide and printable setup handout
    - USER_GUIDE.md: day-to-day operation of the monitor
    - documentation/DESIGN_REFERENCE.md: merges the seven earlier design
    documents, corrected against the code; adds the LabVIEW decode
    - documentation/Eaglehagen_Basic_Setup.pptx: printable handout for
    Dr. Örnhagen, with the Örnhagen logo (ornhagen_logo.jpg)
    - Remove duplicate and superseded documents
2026-09-27 Add stand-alone PC monitor page, downloadable from the device
    - tools/Eaglehagen_Serial_Monitor.html: Web Serial page for Chrome/Edge
    with live values, charts and unlimited CSV recording over USB; accepts
    both output formats (LabVIEW and ASCII) with auto-detection
    - tools/tests: parser tests with a real device capture
    (node tools/tests/test_monitor_parser.js)
    - scripts/embed_monitor_page.py: pre-build script that gzips the page
    into include/MonitorPage.h (generated, git-ignored)
    - Web server: GET /monitor.html serves it as a download; the built-in
    web page gets a "PC monitor page (USB)" Download button
    - main.cpp: correct stale update-rate comments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
    [main.cpp]
2026-09-27 Document the PC monitor page and refresh docs and handout
    - User guide: new section 7 (PC monitor page: WiFi download, then USB),
    port names, troubleshooting and quick-reference updates
    - Design reference: §6.4 PC monitor page, /monitor.html endpoint, build
    script, measured footprint, Arduino IDE notes, tests, corrections
    - Handout: new page on the PC monitor page, "by Teknosofen" footer,
    layout fixes
2026-09-28 Add device photos and mechanical CAD to documentation
    - documentation/Images: photos of the device (IMG_1770, IMG_1771)
    - documentation/Mech CAD: Fusion 360 enclosure model
    (EagleHagen_Gas_analyzer.f3z)
    [EagleHagen_Gas_analyzer.f3z]
2026-09-28 Reference photos and CAD in docs, use enclosure button names
    - Design reference: new §2.7 (enclosure, photos, Fusion 360 model);
    pin table shows the button labels
    - User guide: photo of the unit, links to both photos; buttons called
    "Restart pump" and "Select output" throughout, as labelled on the
    enclosure
    - Handout: same button names on all pages; page 4 shows close-ups of
    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
2026-09-28 Remove unused prototype code (EagleHagen/, _older_stuff/)
    Neither folder was ever part of the build. EagleHagen/ was an early
    ESP8266 sketch whose includes never matched its file names
    (GasAnalyzer.h vs "Gas Analyzer.hpp", AccessPoint.h vs Accesspoint.hpp,
    missing LogoBitmap.h); _older_stuff/MaCO2Parser.cpp is superseded by
    src/MaCO2Parser.cpp. Both remain available in git history (2cba5e9).
    [MaCO2Parser.cpp]
